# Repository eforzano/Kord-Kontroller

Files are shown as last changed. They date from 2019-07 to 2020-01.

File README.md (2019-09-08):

# Kord Kontroller
The Kord Kontroller is a MIDI controller that maps common chordal relationships in Western music theory. This pattern mapping allows you to play major, minor, and other common chords in the same pattern regardless of the key! The newest design is focusing on an ergonomic design based on your hand. For more information check out the [Hackaday page](https://hackaday.io/project/161105-kord-kontroller). 

## Theory  
The Kord Kontroller is a musical interface that maps the notes in the same pattern rather than being forced to memorize patterns that are caused by restrictions of acoustical phenomena (i.e. strings and metal). The advantage of being able to map the buttons in an intuitive way encourages music creation and lowers the threshold of learning music. The Kord Kontroller is laid out into two sections: the key selector area and tonal selector area. 

The three type of key selectors are a piano key selector, a circle of fifths key selector, and an isomorphic key selector. Once you select a note on the key selector, for example a C, this maps the tonal selectors in a consistent pattern regardless of the key. The tonal selectors are mapped to the 1 3 5 7 9 11 13 (C E G B D F A) of the key selected like below: 

```
3  5  7  9  11  13

1  
```

The 1 (or the root) and these corresponding notes are selected because they are really common chordal relationships. The 1 is mapped topographically lower on the controller in order to match your hand lay out and since it is commonly played with your thumb. This allows you to play major chords and other common chords in the same pattern regardless of the key!

We did not want to only let you play major chords so we added the flat and sharp equivalent rows: b3 b5 b7 b9 b11 b13 and #3 #5 #7 #9 #11 #13. (Note: we understand that it is not common to refer to the 4 as a #3 or the 8 as #7, but this is more to emphasize the relationships). This allows one to play minor chords and other chords in the exact same way as well. We also added some other common notes like the 2 b2 12 14 etc. We also added octave buttons and mode changes to switch the key selectors. This ended up with this final layout:
```
                       12    14
      4  #5   8   #9  #11   b14

2     3    5   7    9  11    13

b2    b3   b5  b7   b9 10   b13

1               6           #12

```

For any questions or comments email: eforzano at gmail.com

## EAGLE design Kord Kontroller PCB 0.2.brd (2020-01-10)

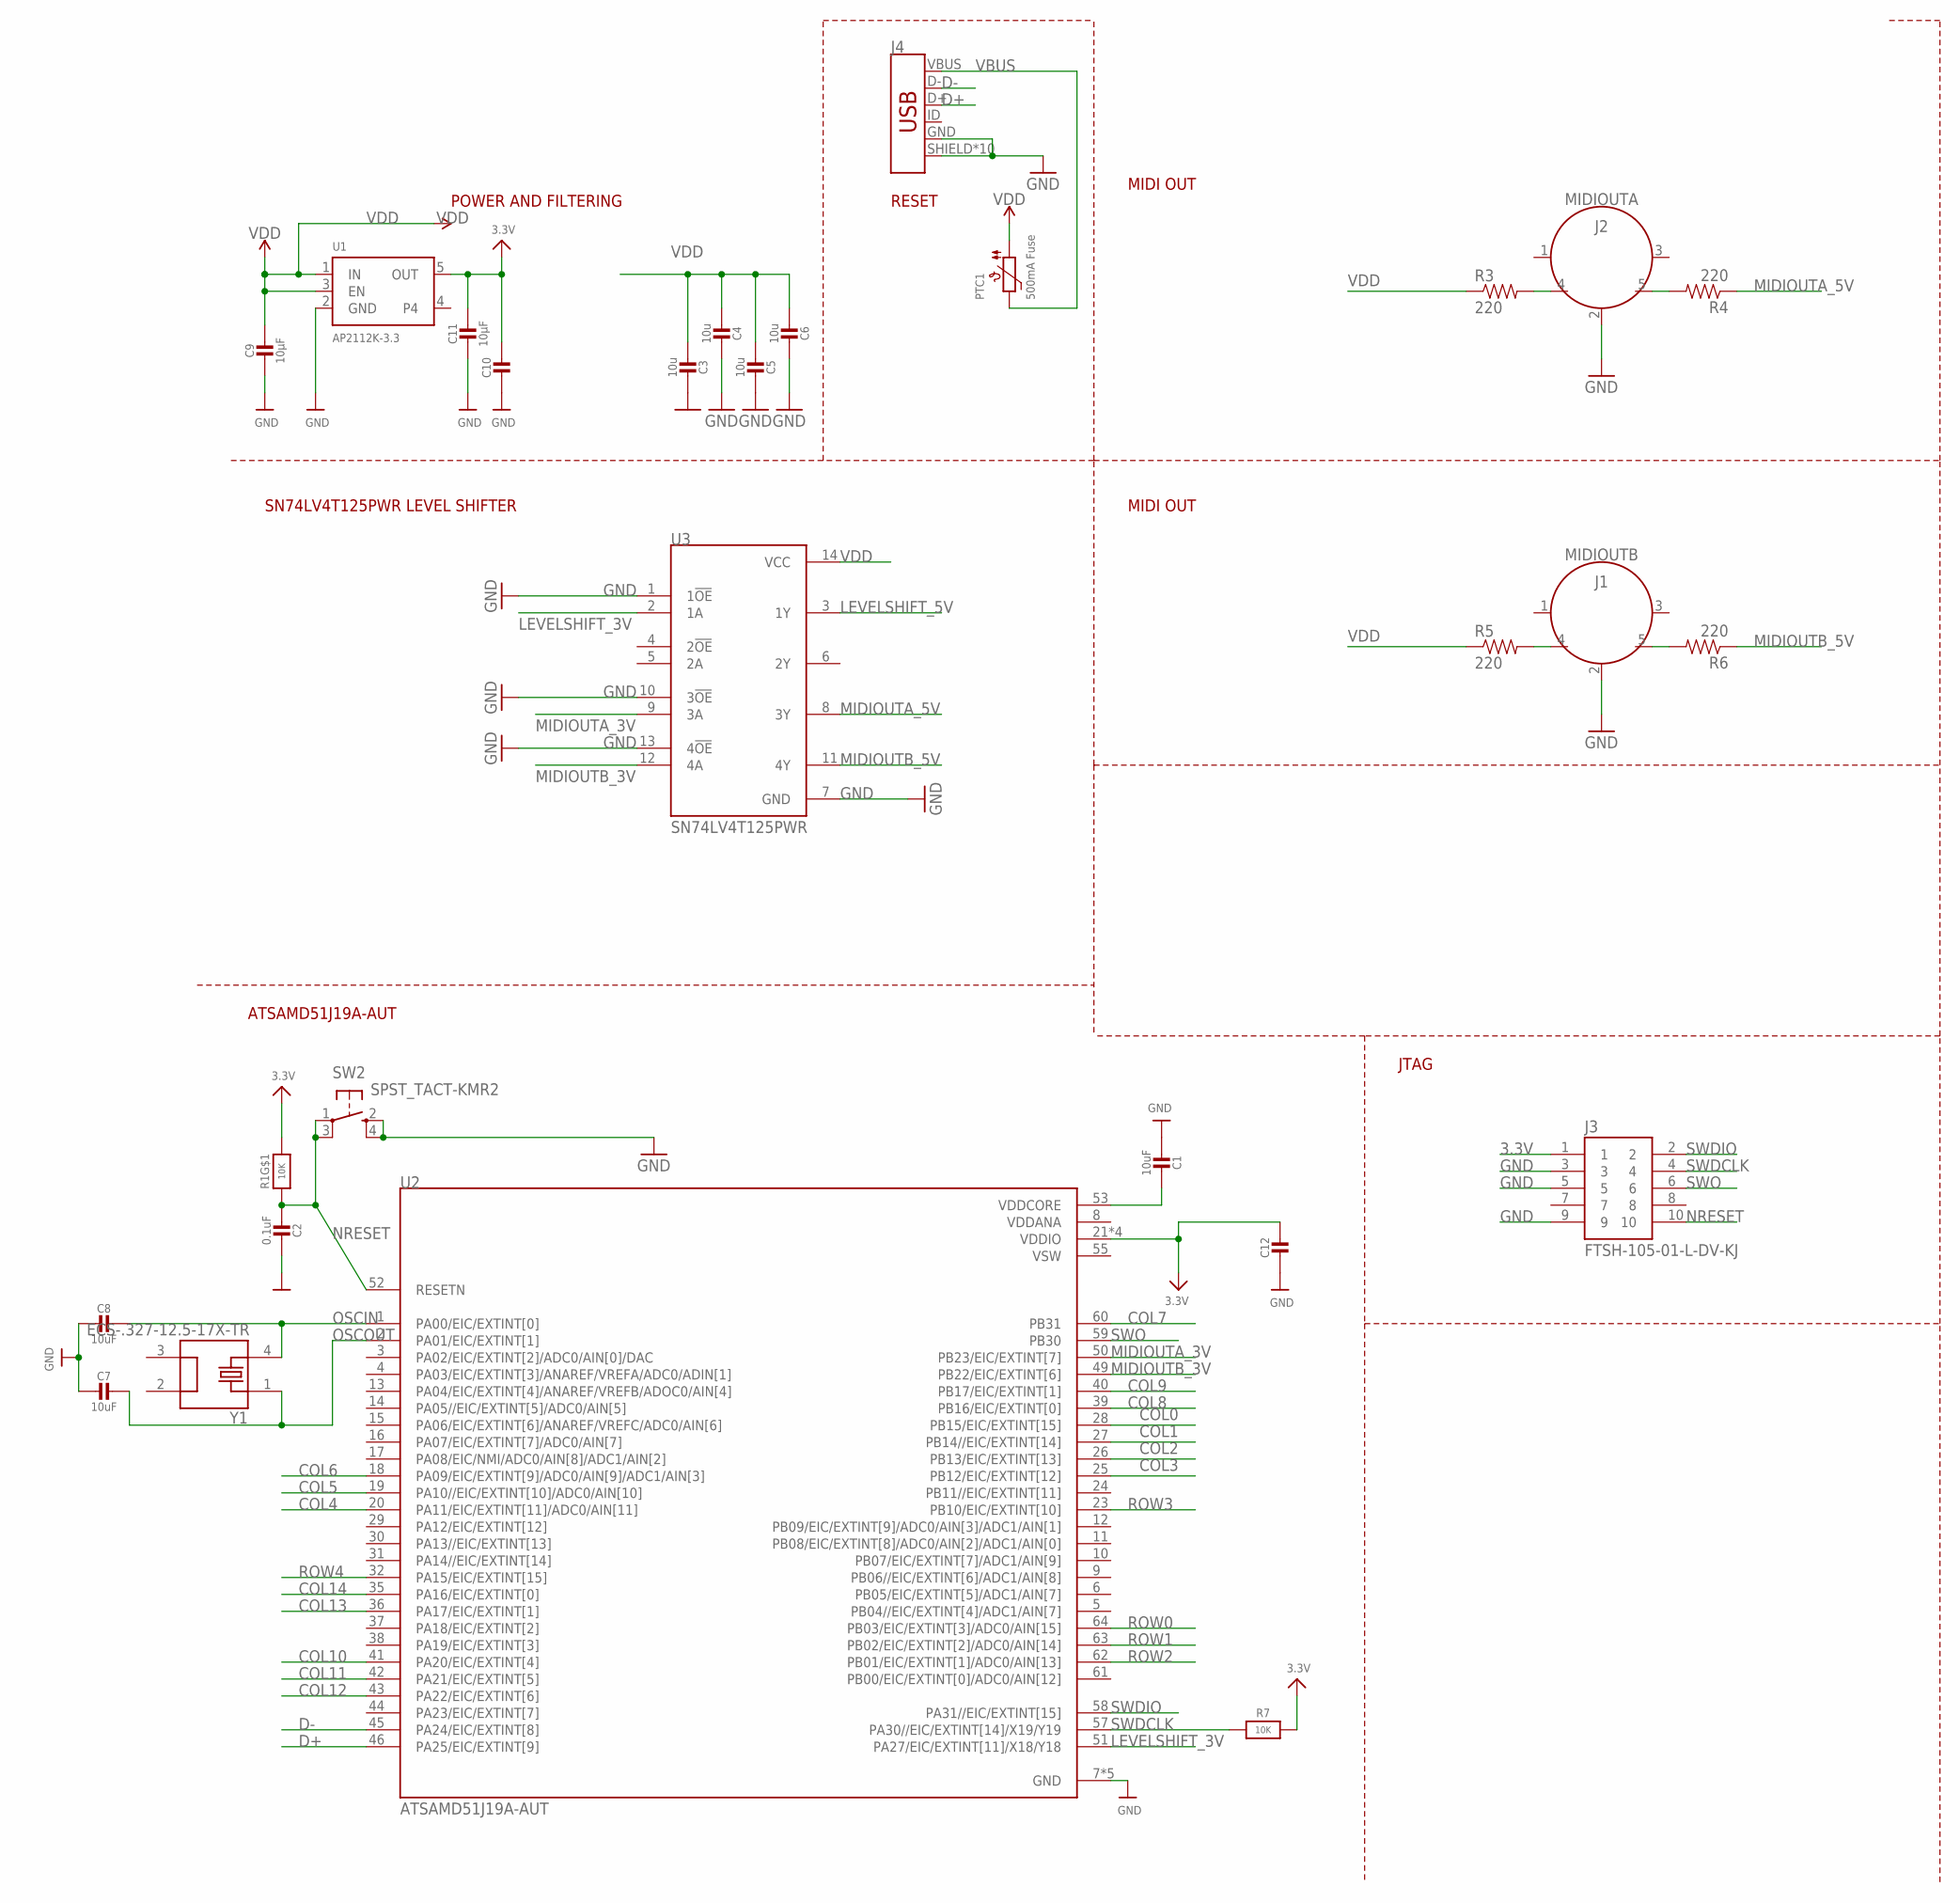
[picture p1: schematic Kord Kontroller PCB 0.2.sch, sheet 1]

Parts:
C1, C7, C8: 10uF; 0805-NO
C2: 0.1uF; 0603-NO
C3, C4, C5, C6: 10u; 0805-NO
C9, C11: 10µF; 0805-NO
C10, C12: 1uF; 0603-NO
J1: MIDIOUTB; 5-PIN-DIN-RA-PCB-NEW
J2: MIDIOUTA; 5-PIN-DIN-RA-PCB-NEW
J3: FTSH-105-01-L-DV-KJ; SAMTEC_FTSH-105-01-L-DV-K
J4: USB_MICRO-B_HALF_PTH_MILL; USB-MICROB-PTH-MILL
PTC1: 500mA Fuse; 1206
R1: 10K; RESPACK_4X0603
R3, R4, R5, R6: 220; 0603-RES
R7: 10K; 0603-NO
SW2: SPST_TACT-KMR2; KMR2
U1: AP2112K-3.3; SOT23-5
U2: ATSAMD51J19A-AUT; QFP50P1200X1200X120-64N
U3: SN74LV4T125PWR; SOP65P640X120-14N
Y1: ECS-.327-12.5-17X-TR; XTAL_ECS-.327-12.5-17X-TR

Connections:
3.3V: C10.1, C11.1, C12.1, J3.1, R1.8 (2), R7.2, U1.5 (OUT), U2.21 (VDDIO), U2.34 (VDDIO), U2.48 (VDDIO), U2.56 (VDDIO)
COL0: U2.28 (PB15/EIC/EXTINT[15]); also elsewhere on the board
COL1: U2.27 (PB14//EIC/EXTINT[14]); also elsewhere on the board
COL2: U2.26 (PB13/EIC/EXTINT[13]); also elsewhere on the board
COL3: U2.25 (PB12/EIC/EXTINT[12]); also elsewhere on the board
COL4: U2.20 (PA11/EIC/EXTINT[11]/ADC0/AIN[11]); also elsewhere on the board
COL5: U2.19 (PA10//EIC/EXTINT[10]/ADC0/AIN[10]); also elsewhere on the board
COL6: U2.18 (PA09/EIC/EXTINT[9]/ADC0/AIN[9]/ADC1/AIN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); also elsewhere on the board
COL7: U2.60 (PB31); also elsewhere on the board
COL8: U2.39 (PB16/EIC/EXTINT[0]); also elsewhere on the board
COL9: U2.40 (PB17/EIC/EXTINT[1]); also elsewhere on the board
COL10: U2.41 (PA20/EIC/EXTINT[4]); also elsewhere on the board
COL11: U2.42 (PA21/EIC/EXTINT[5]); also elsewhere on the board
COL12: U2.43 (PA22/EIC/EXTINT[6]); also elsewhere on the board
COL13: U2.36 (PA17/EIC/EXTINT[1]); also elsewhere on the board
COL14: U2.35 (PA16/EIC/EXTINT[0]); also elsewhere on the board
D+: J4.D+, U2.46 (PA25/EIC/EXTINT[9])
D-: J4.D-, U2.45 (PA24/EIC/EXTINT[8])
GND: C1.2, C2.1, C3.1, C4.1, C5.1, C6.1, C7.2, C8.2, C9.2, C10.2, C11.2, C12.2, J1.2, J2.2, J3.3, J3.5, J3.9, J4.GND, J4.SHIELD, J4.SHIELD2 (SHIELD), J4.SHIELD3 (SHIELD), J4.SHIELD4 (SHIELD), J4.SHIELD5 (SHIELD), J4.SHIELD6 (SHIELD), J4.SHIELD7 (SHIELD), J4.SHIELD8 (SHIELD), J4.SHIELD9 (SHIELD), J4.SHIELD10 (SHIELD), SW2.2 (S), SW2.4 (S1), U1.2 (GND), U2.7 (GND), U2.22 (GND), U2.33 (GND), U2.47 (GND), U2.54 (GND), U3.1 (1!OE), U3.7 (GND), U3.10 (3!OE), U3.13 (4!OE); also elsewhere on the board
LEVELSHIFT_3V: U2.51 (PA27/EIC/EXTINT[11]/X18/Y18), U3.2 (1A)
LEVELSHIFT_5V: U3.3 (1Y); also elsewhere on the board
MIDIOUTA_3V: U2.50 (PB23/EIC/EXTINT[7]), U3.9 (3A)
MIDIOUTA_5V: R4.1, U3.8 (3Y)
MIDIOUTB_3V: U2.49 (PB22/EIC/EXTINT[6]), U3.12 (4A)
MIDIOUTB_5V: R6.1, U3.11 (4Y)
unnamed: J1.5, R6.2
unnamed: J1.4, R5.2
unnamed: J2.5, R4.2
unnamed: J2.4, R3.2
NRESET: C2.2, J3.10, R1.1, SW2.1, SW2.3 (P1), U2.52 (RESETN)
OSCIN: C8.1, U2.1 (PA00/EIC/EXTINT[0]), Y1.4
OSCOUT: C7.1, U2.2 (PA01/EIC/EXTINT[1]), Y1.1
ROW0: U2.64 (PB03/EIC/EXTINT[3]/ADC0/AIN[15]); also elsewhere on the board
ROW1: U2.63 (PB02/EIC/EXTINT[2]/ADC0/AIN[14]); also elsewhere on the board
ROW2: U2.62 (PB01/EIC/EXTINT[1]/ADC0/AIN[13]); also elsewhere on the board
ROW3: U2.23 (PB10/EIC/EXTINT[10]); also elsewhere on the board
ROW4: U2.32 (PA15/EIC/EXTINT[15]); also elsewhere on the board
SWDCLK: J3.4, R7.1, U2.57 (PA30//EIC/EXTINT[14]/X19/Y19)
SWDIO: J3.2, U2.58 (PA31//EIC/EXTINT[15])
SWO: J3.6, U2.59 (PB30)
VBUS: J4.VBUS, PTC1.2
VDD: C3.2, C4.2, C5.2, C6.2, C9.1, PTC1.1, R3.1, R5.1, U1.1 (IN), U1.3 (EN), U3.14 (VCC); also elsewhere on the board
VDDANA: U2.8 (VDDANA)
VDDCORE1: C1.1, U2.53 (VDDCORE)
VSW: U2.55 (VSW)

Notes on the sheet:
POWER AND FILTERING
RESET
MIDI OUT
SN74LV4T125PWR LEVEL SHIFTER
JTAG
ATSAMD51J19A-AUT

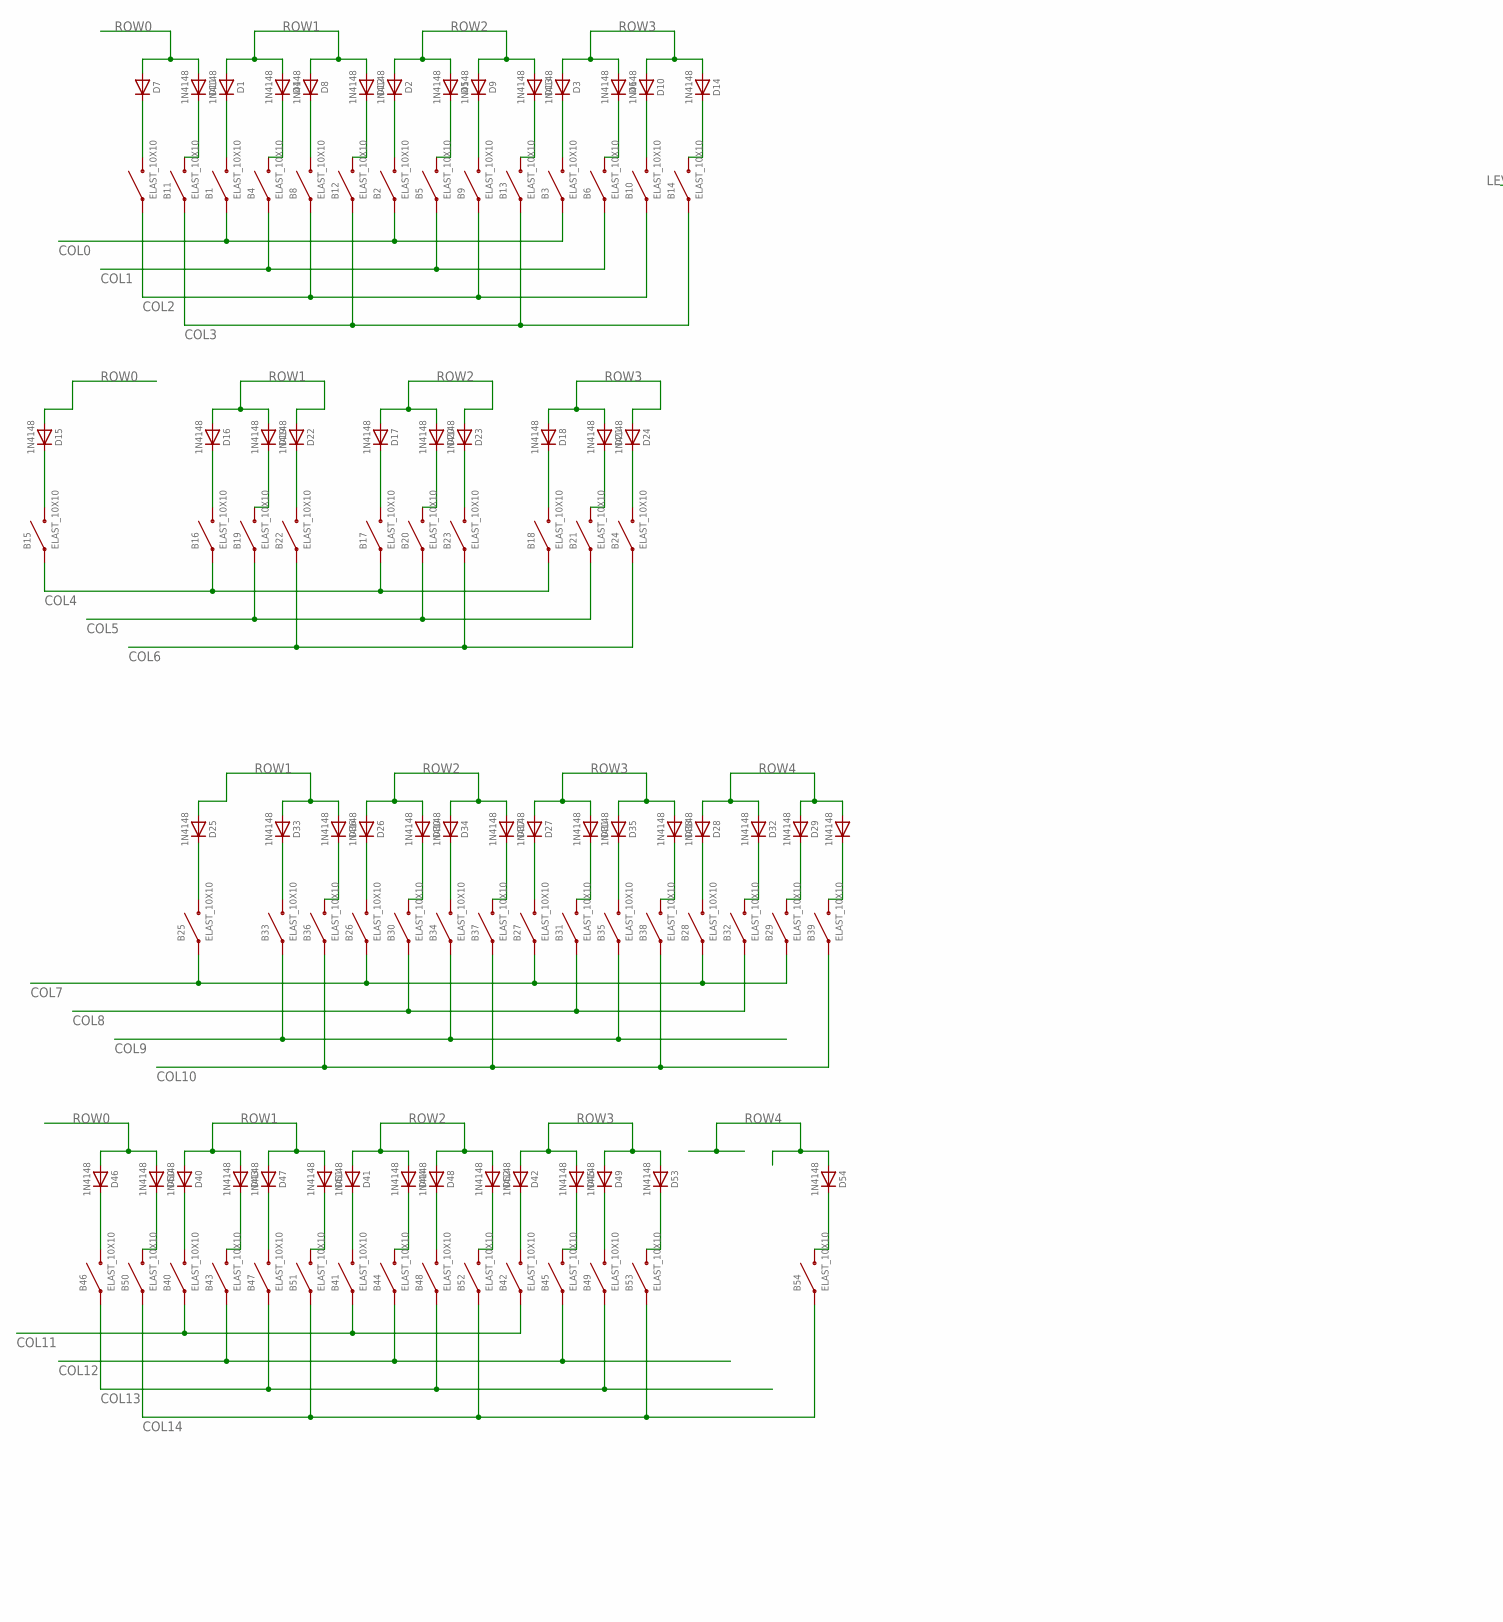
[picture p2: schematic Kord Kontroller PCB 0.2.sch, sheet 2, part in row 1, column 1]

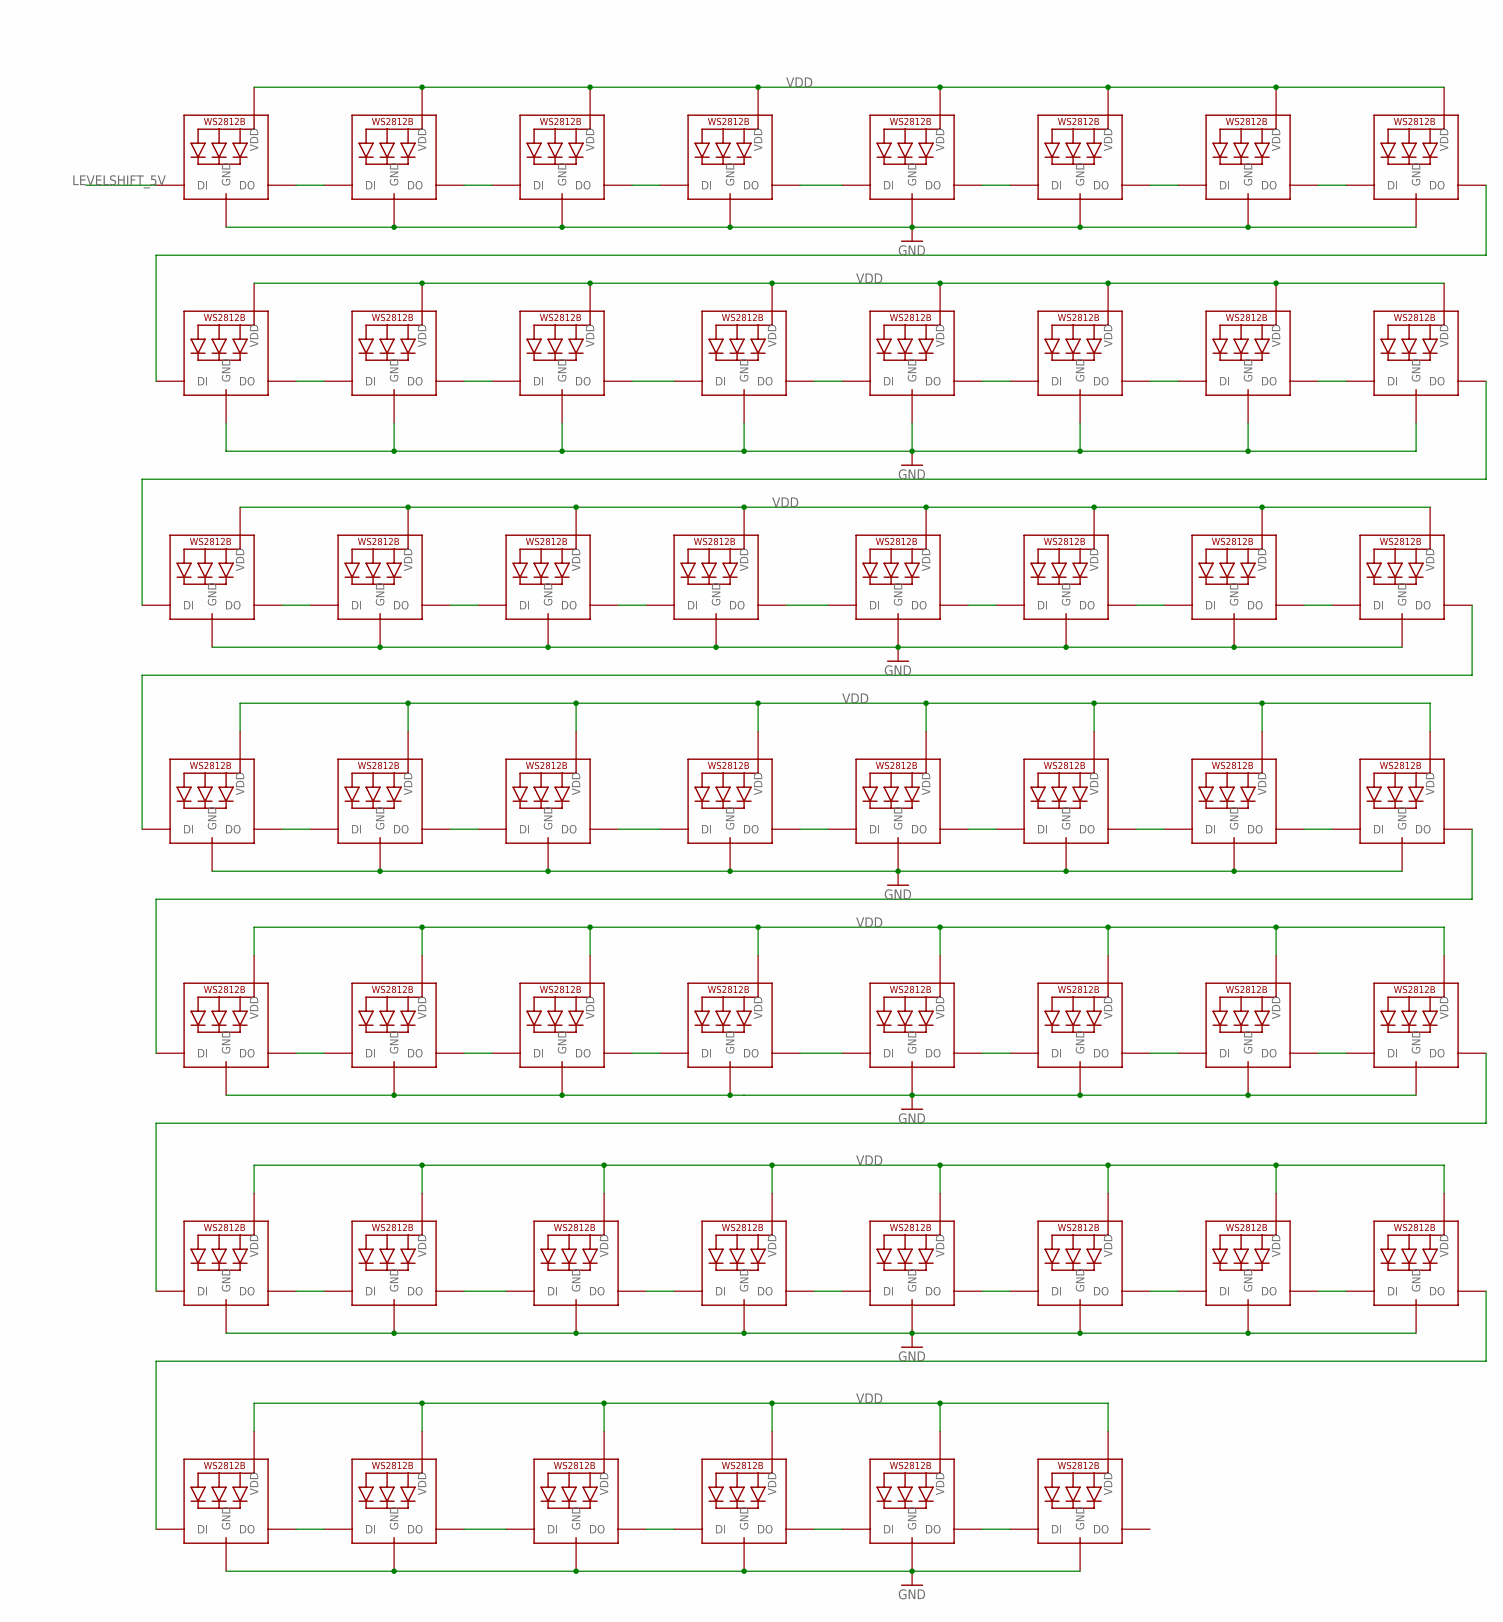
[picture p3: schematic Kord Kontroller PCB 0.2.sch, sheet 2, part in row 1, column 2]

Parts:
B1, B2, B3, B4, B5, B6, B7, B8, B9, B10, B11, B12, B13, B14, B15, B16, B17, B18, B19, B20, B21, B22, B23, B24, B25, B26, B27, B28, B29, B30, B31, B32, B33, B34, B35, B36, B37, B38, B39, B40, B41, B42, B43, B44, B45, B46, B47, B48, B49, B50, B51, B52, B53, B54: ELAST_10X10; ELAST_PAD_SQUARE_10MM_4X4WIDE
D1, D2, D3, D4, D5, D6, D7, D8, D9, D10, D11, D12, D13, D14, D15, D16, D17, D18, D19, D20, D21, D22, D23, D24, D25, D26, D27, D28, D29, D30, D31, D32, D33, D34, D35, D36, D37, D38, D39, D40, D41, D42, D43, D44, D45, D46, D47, D48, D49, D50, D51, D52, D53, D54: 1N4148; SOD-323
LED1, LED2, LED3, LED4, LED5, LED6, LED7, LED8, LED9, LED10, LED11, LED12, LED13, LED14, LED15, LED16, LED17, LED18, LED19, LED20, LED21, LED22, LED23, LED24, LED25, LED26, LED27, LED28, LED29, LED30, LED31, LED32, LED33, LED34, LED35, LED36, LED37, LED38, LED39, LED40, LED41, LED42, LED43, LED44, LED45, LED46, LED47, LED48, LED49, LED50, LED51, LED52, LED53, LED54: WS2812B3535; LED3535

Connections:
COL0: B1.P$1, B2.P$1, B3.P$1; also elsewhere on the board
COL1: B4.P$1, B5.P$1, B6.P$1; also elsewhere on the board
COL2: B7.P$1, B8.P$1, B9.P$1, B10.P$1; also elsewhere on the board
COL3: B11.P$1, B12.P$1, B13.P$1, B14.P$1; also elsewhere on the board
COL4: B15.P$1, B16.P$1, B17.P$1, B18.P$1; also elsewhere on the board
COL5: B19.P$1, B20.P$1, B21.P$1; also elsewhere on the board
COL6: B22.P$1, B23.P$1, B24.P$1; also elsewhere on the board
COL7: B25.P$1, B26.P$1, B27.P$1, B28.P$1, B29.P$1; also elsewhere on the board
COL8: B30.P$1, B31.P$1, B32.P$1; also elsewhere on the board
COL9: B33.P$1, B34.P$1, B35.P$1; also elsewhere on the board
COL10: B36.P$1, B37.P$1, B38.P$1, B39.P$1; also elsewhere on the board
COL11: B40.P$1, B41.P$1, B42.P$1; also elsewhere on the board
COL12: B43.P$1, B44.P$1, B45.P$1; also elsewhere on the board
COL13: B46.P$1, B47.P$1, B48.P$1, B49.P$1; also elsewhere on the board
COL14: B50.P$1, B51.P$1, B52.P$1, B53.P$1, B54.P$1; also elsewhere on the board
GND: LED1.4 (GND), LED2.4 (GND), LED3.4 (GND), LED4.4 (GND), LED5.4 (GND), LED6.4 (GND), LED7.4 (GND), LED8.4 (GND), LED9.4 (GND), LED10.4 (GND), LED11.4 (GND), LED12.4 (GND), LED13.4 (GND), LED14.4 (GND), LED15.4 (GND), LED16.4 (GND), LED17.4 (GND), LED18.4 (GND), LED19.4 (GND), LED20.4 (GND), LED21.4 (GND), LED22.4 (GND), LED23.4 (GND), LED24.4 (GND), LED25.4 (GND), LED26.4 (GND), LED27.4 (GND), LED28.4 (GND), LED29.4 (GND), LED30.4 (GND), LED31.4 (GND), LED32.4 (GND), LED33.4 (GND), LED34.4 (GND), LED35.4 (GND), LED36.4 (GND), LED37.4 (GND), LED38.4 (GND), LED39.4 (GND), LED40.4 (GND), LED41.4 (GND), LED42.4 (GND), LED43.4 (GND), LED44.4 (GND), LED45.4 (GND), LED46.4 (GND), LED47.4 (GND), LED48.4 (GND), LED49.4 (GND), LED50.4 (GND), LED51.4 (GND), LED52.4 (GND), LED53.4 (GND), LED54.4 (GND); also elsewhere on the board
LEVELSHIFT_5V: LED1.1 (DI); also elsewhere on the board
unnamed: LED36.3 (DO), LED37.1 (DI)
unnamed: B7.P$2, D7.C
unnamed: B11.P$2, D11.C
unnamed: B1.P$2, D1.C
unnamed: LED17.3 (DO), LED18.1 (DI)
unnamed: LED18.3 (DO), LED19.1 (DI)
unnamed: B4.P$2, D4.C
unnamed: LED19.3 (DO), LED20.1 (DI)
unnamed: LED1.3 (DO), LED2.1 (DI)
unnamed: LED2.3 (DO), LED3.1 (DI)
unnamed: LED3.3 (DO), LED4.1 (DI)
unnamed: LED4.3 (DO), LED5.1 (DI)
unnamed: B8.P$2, D8.C
unnamed: LED5.3 (DO), LED6.1 (DI)
unnamed: LED6.3 (DO), LED7.1 (DI)
unnamed: B12.P$2, D12.C
unnamed: LED7.3 (DO), LED8.1 (DI)
unnamed: B2.P$2, D2.C
unnamed: LED8.3 (DO), LED9.1 (DI)
unnamed: B5.P$2, D5.C
unnamed: B9.P$2, D9.C
unnamed: B13.P$2, D13.C
unnamed: B3.P$2, D3.C
unnamed: B6.P$2, D6.C
unnamed: B10.P$2, D10.C
unnamed: B14.P$2, D14.C
unnamed: LED9.3 (DO), LED10.1 (DI)
unnamed: LED10.3 (DO), LED11.1 (DI)
unnamed: LED11.3 (DO), LED12.1 (DI)
unnamed: LED12.3 (DO), LED13.1 (DI)
unnamed: LED13.3 (DO), LED14.1 (DI)
unnamed: LED14.3 (DO), LED15.1 (DI)
unnamed: LED15.3 (DO), LED16.1 (DI)
unnamed: LED20.3 (DO), LED21.1 (DI)
unnamed: LED21.3 (DO), LED22.1 (DI)
unnamed: LED22.3 (DO), LED23.1 (DI)
unnamed: LED23.3 (DO), LED24.1 (DI)
unnamed: LED24.3 (DO), LED25.1 (DI)
unnamed: LED25.3 (DO), LED26.1 (DI)
unnamed: LED26.3 (DO), LED27.1 (DI)
unnamed: LED28.3 (DO), LED29.1 (DI)
unnamed: LED27.3 (DO), LED28.1 (DI)
unnamed: LED29.3 (DO), LED30.1 (DI)
unnamed: LED30.3 (DO), LED31.1 (DI)
unnamed: LED31.3 (DO), LED32.1 (DI)
unnamed: B15.P$2, D15.C
unnamed: LED34.3 (DO), LED35.1 (DI)
unnamed: LED35.3 (DO), LED36.1 (DI)
unnamed: LED44.3 (DO), LED45.1 (DI)
unnamed: B16.P$2, D16.C
unnamed: B19.P$2, D19.C
unnamed: B22.P$2, D22.C
unnamed: LED43.3 (DO), LED44.1 (DI)
unnamed: B17.P$2, D17.C
unnamed: B20.P$2, D20.C
unnamed: B23.P$2, D23.C
unnamed: LED42.3 (DO), LED43.1 (DI)
unnamed: B18.P$2, D18.C
unnamed: B21.P$2, D21.C
unnamed: B24.P$2, D24.C
unnamed: LED16.3 (DO), LED17.1 (DI)
unnamed: LED50.3 (DO), LED51.1 (DI)
unnamed: LED51.3 (DO), LED52.1 (DI)
unnamed: LED52.3 (DO), LED53.1 (DI)
unnamed: B29.P$2, D29.C
unnamed: B25.P$2, D25.C
unnamed: B33.P$2, D33.C
unnamed: B36.P$2, D36.C
unnamed: B26.P$2, D26.C
unnamed: B30.P$2, D30.C
unnamed: B34.P$2, D34.C
unnamed: B37.P$2, D37.C
unnamed: B27.P$2, D27.C
unnamed: B31.P$2, D31.C
unnamed: B35.P$2, D35.C
unnamed: B38.P$2, D38.C
unnamed: LED33.3 (DO), LED34.1 (DI)
unnamed: LED37.3 (DO), LED38.1 (DI)
unnamed: LED38.3 (DO), LED39.1 (DI)
unnamed: LED39.3 (DO), LED40.1 (DI)
unnamed: LED41.3 (DO), LED42.1 (DI)
unnamed: LED45.3 (DO), LED46.1 (DI)
unnamed: LED46.3 (DO), LED47.1 (DI)
unnamed: LED47.3 (DO), LED48.1 (DI)
unnamed: LED49.3 (DO), LED50.1 (DI)
unnamed: LED53.3 (DO), LED54.1 (DI)
unnamed: LED40.3 (DO), LED41.1 (DI)
unnamed: LED48.3 (DO), LED49.1 (DI)
unnamed: LED32.3 (DO), LED33.1 (DI)
unnamed: B46.P$2, D46.C
unnamed: B50.P$2, D50.C
unnamed: B40.P$2, D40.C
unnamed: B43.P$2, D43.C
unnamed: B47.P$2, D47.C
unnamed: B51.P$2, D51.C
unnamed: B41.P$2, D41.C
unnamed: B44.P$2, D44.C
unnamed: B48.P$2, D48.C
unnamed: B52.P$2, D52.C
unnamed: B42.P$2, D42.C
unnamed: B45.P$2, D45.C
unnamed: B49.P$2, D49.C
unnamed: B53.P$2, D53.C
unnamed: B28.P$2, D28.C
unnamed: B32.P$2, D32.C
unnamed: B39.P$2, D39.C
unnamed: B54.P$2, D54.C
ROW0: D7.A, D11.A, D15.A, D46.A, D50.A; also elsewhere on the board
ROW1: D1.A, D4.A, D8.A, D12.A, D16.A, D19.A, D22.A, D25.A, D33.A, D36.A, D40.A, D43.A, D47.A, D51.A; also elsewhere on the board
ROW2: D2.A, D5.A, D9.A, D13.A, D17.A, D20.A, D23.A, D26.A, D30.A, D34.A, D37.A, D41.A, D44.A, D48.A, D52.A; also elsewhere on the board
ROW3: D3.A, D6.A, D10.A, D14.A, D18.A, D21.A, D24.A, D27.A, D31.A, D35.A, D38.A, D42.A, D45.A, D49.A, D53.A; also elsewhere on the board
ROW4: D28.A, D29.A, D32.A, D39.A, D54.A; also elsewhere on the board
VDD: LED1.2 (VDD), LED2.2 (VDD), LED3.2 (VDD), LED4.2 (VDD), LED5.2 (VDD), LED6.2 (VDD), LED7.2 (VDD), LED8.2 (VDD), LED9.2 (VDD), LED10.2 (VDD), LED11.2 (VDD), LED12.2 (VDD), LED13.2 (VDD), LED14.2 (VDD), LED15.2 (VDD), LED16.2 (VDD), LED17.2 (VDD), LED18.2 (VDD), LED19.2 (VDD), LED20.2 (VDD), LED21.2 (VDD), LED22.2 (VDD), LED23.2 (VDD), LED24.2 (VDD), LED25.2 (VDD), LED26.2 (VDD), LED27.2 (VDD), LED28.2 (VDD), LED29.2 (VDD), LED30.2 (VDD), LED31.2 (VDD), LED32.2 (VDD), LED33.2 (VDD), LED34.2 (VDD), LED35.2 (VDD), LED36.2 (VDD), LED37.2 (VDD), LED38.2 (VDD), LED39.2 (VDD), LED40.2 (VDD), LED41.2 (VDD), LED42.2 (VDD), LED43.2 (VDD), LED44.2 (VDD), LED45.2 (VDD), LED46.2 (VDD), LED47.2 (VDD), LED48.2 (VDD), LED49.2 (VDD), LED50.2 (VDD), LED51.2 (VDD), LED52.2 (VDD), LED53.2 (VDD), LED54.2 (VDD); also elsewhere on the board

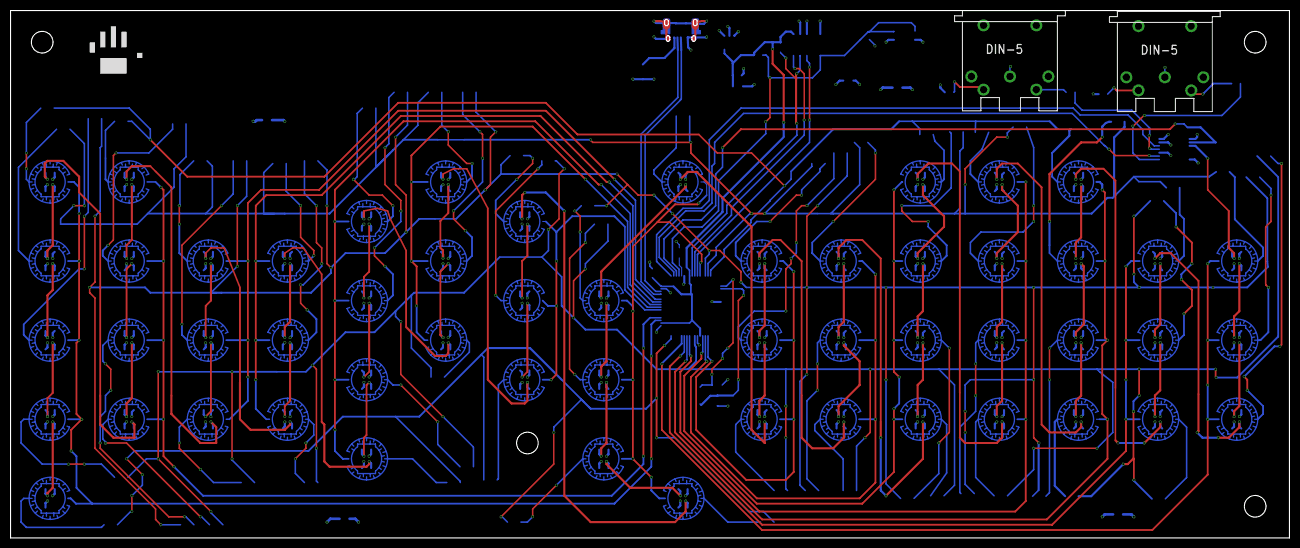
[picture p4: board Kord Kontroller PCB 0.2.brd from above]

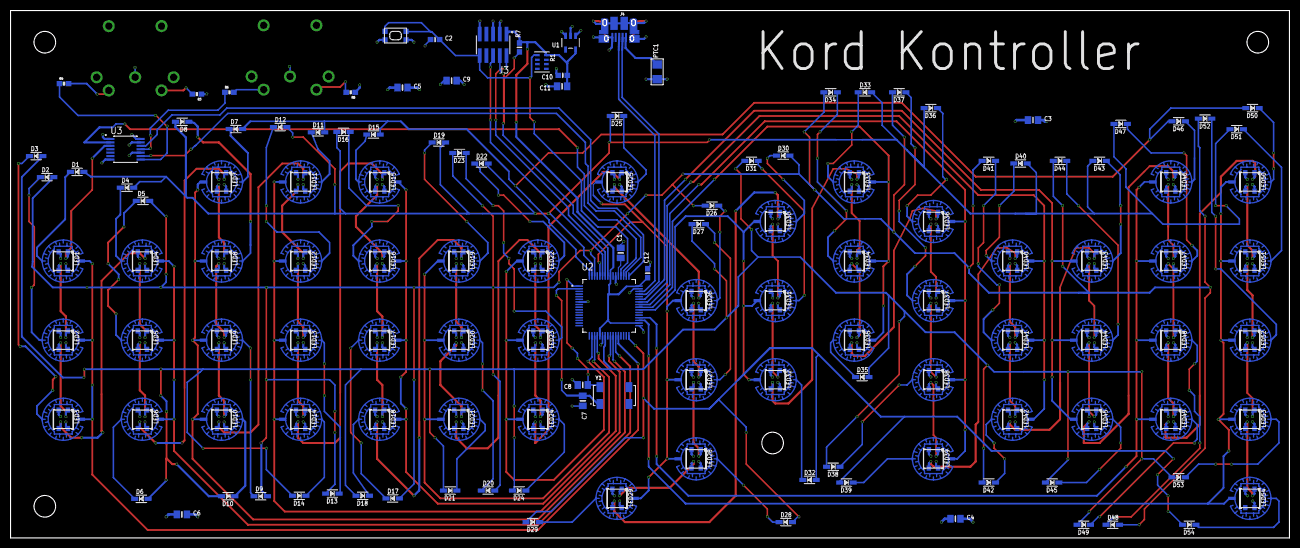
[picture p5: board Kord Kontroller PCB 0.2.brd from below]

Board: 4 copper layers, 242.5 x 100.0 mm, 190 parts (188 on the bottom side), 150 nets.

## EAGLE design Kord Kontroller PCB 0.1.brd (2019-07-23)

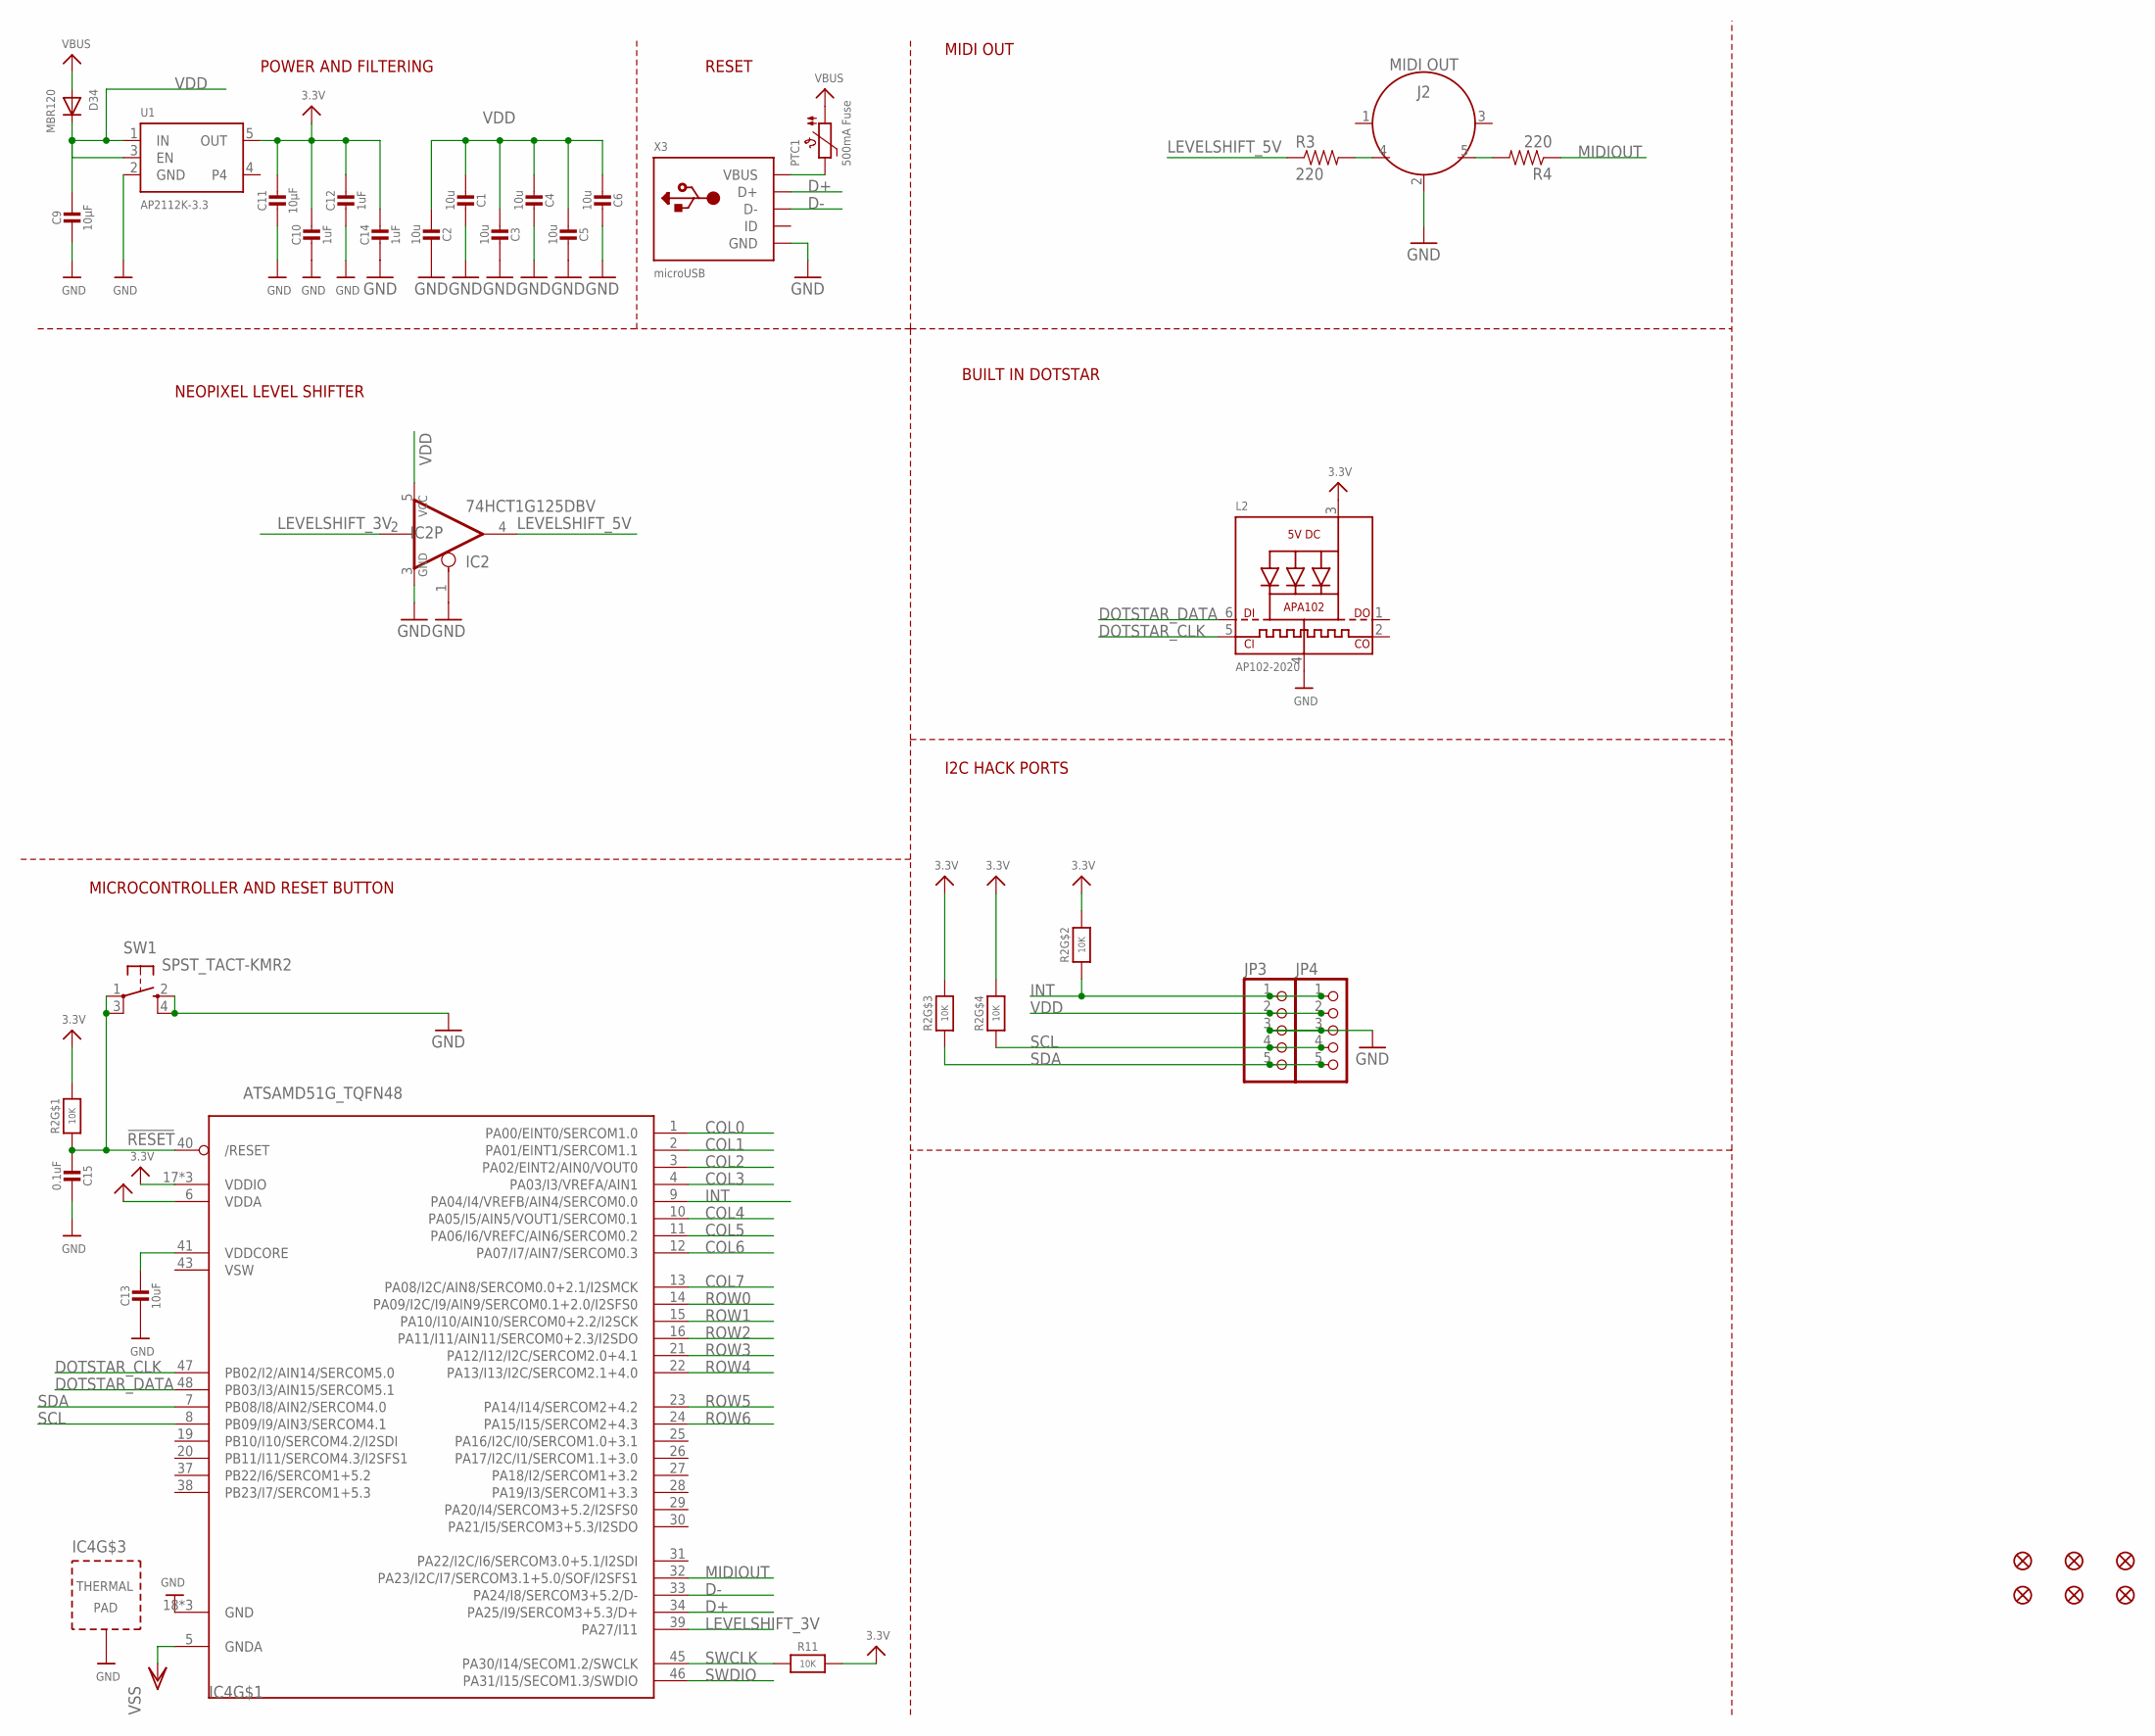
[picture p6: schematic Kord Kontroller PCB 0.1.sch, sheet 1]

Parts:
C1, C2, C3, C4, C5, C6: 10u; 0805-NO
C9, C11: 10µF; 0805-NO
C10, C12, C14: 1uF; 0603-NO
C13: 10uF; 0805-NO
C15: 0.1uF; 0603-NO
D34: MBR120; SOD-123FL
FID1, FID2, FID3, FID4, FID5, FID6: FIDUCIAL_1MM
IC2: 74HCT1G125DBV; SOT23-5
IC4: ATSAMD51G_TQFN48; TQFN48_7MM
J2: MIDI OUT; 5-PIN-DIN-RA-PCB-NEW
JP3, JP4: HEADER-1X5EDGESMT; 5P_EDGECONNECT
L2: AP102-2020; APA102_2020
PTC1: 500mA Fuse; 1206
R2: 10K; RESPACK_4X0603
R3, R4: 220; 0603-RES
R11: 10K; 0603-NO
SW1: SPST_TACT-KMR2; KMR2
U1: AP2112K-3.3; SOT23-5
X3: microUSB; 4UCONN_20329_NARROW

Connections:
3.3V: C10.1, C11.1, C12.1, C14.1, IC4.17 (VDDIO), IC4.36 (VDDIO), IC4.44 (VDDIO), L2.3 (VDD), R2.5 (2), R2.6 (2), R2.7 (2), R2.8 (2), R11.2, U1.5 (OUT)
!RESET: C15.2, IC4.40 (/RESET), R2.1, SW1.1, SW1.3 (P1)
AVDD: IC4.6 (VDDA)
COL0: IC4.1 (PA00/EINT0/SERCOM1.0); also elsewhere on the board
COL1: IC4.2 (PA01/EINT1/SERCOM1.1); also elsewhere on the board
COL2: IC4.3 (PA02/EINT2/AIN0/VOUT0); also elsewhere on the board
COL3: IC4.4 (PA03/I3/VREFA/AIN1); also elsewhere on the board
COL4: IC4.10 (PA05/I5/AIN5/VOUT1/SERCOM0.1); also elsewhere on the board
COL5: IC4.11 (PA06/I6/VREFC/AIN6/SERCOM0.2); also elsewhere on the board
COL6: IC4.12 (PA07/I7/AIN7/SERCOM0.3); also elsewhere on the board
COL7: IC4.13 (PA08/I2C/AIN8/SERCOM0.0+2.1/I2SMCK); also elsewhere on the board
D+: IC4.34 (PA25/I9/SERCOM3+5.3/D+), X3.D+
D-: IC4.33 (PA24/I8/SERCOM3+5.2/D-), X3.D-
DOTSTAR_CLK: IC4.47 (PB02/I2/AIN14/SERCOM5.0), L2.5 (CKI)
DOTSTAR_DATA: IC4.48 (PB03/I3/AIN15/SERCOM5.1), L2.6 (DI)
GND: C1.1, C2.1, C3.1, C4.1, C5.1, C6.1, C9.2, C10.2, C11.2, C12.2, C13.2, C14.2, C15.1, IC2.1 (OE), IC2.3 (GND), IC4.18 (GND), IC4.35 (GND), IC4.42 (GND), IC4.THERMAL (TP), J2.2, JP3.3, JP4.3, L2.4 (GND), SW1.2 (S), SW1.4 (S1), U1.2 (GND), X3.BASE@1 (GND), X3.BASE@2 (GND), X3.GND, X3.SPRT@1 (GND), X3.SPRT@2 (GND), X3.SPRT@3 (GND), X3.SPRT@4 (GND); also elsewhere on the board
INT: IC4.9 (PA04/I4/VREFB/AIN4/SERCOM0.0), JP3.1, JP4.1, R2.2 (1)
unnamed: PTC1.2, X3.VBUS
NEOPIXEL_3V: IC2.2 (I), IC4.39 (PA27/I11); also elsewhere on the board
unnamed: IC2.4 (O), R3.1
unnamed: J2.4, R3.2
unnamed: J2.5, R4.2
unnamed: IC4.32 (PA23/I2C/I7/SERCOM3.1+5.0/SOF/I2SFS1), R4.1
ROW0: IC4.14 (PA09/I2C/I9/AIN9/SERCOM0.1+2.0/I2SFS0); also elsewhere on the board
ROW1: IC4.15 (PA10/I10/AIN10/SERCOM0+2.2/I2SCK); also elsewhere on the board
ROW2: IC4.16 (PA11/I11/AIN11/SERCOM0+2.3/I2SDO); also elsewhere on the board
ROW3: IC4.21 (PA12/I12/I2C/SERCOM2.0+4.1); also elsewhere on the board
ROW4: IC4.22 (PA13/I13/I2C/SERCOM2.1+4.0); also elsewhere on the board
ROW5: IC4.23 (PA14/I14/SERCOM2+4.2); also elsewhere on the board
ROW6: IC4.24 (PA15/I15/SERCOM2+4.3); also elsewhere on the board
SCL: IC4.8 (PB09/I9/AIN3/SERCOM4.1), JP3.4, JP4.4, R2.4 (1)
SDA: IC4.7 (PB08/I8/AIN2/SERCOM4.0), JP3.5, JP4.5, R2.3 (1)
SWCLK: IC4.45 (PA30/I14/SECOM1.2/SWCLK), R11.1
SWDIO: IC4.46 (PA31/I15/SECOM1.3/SWDIO)
VBUS: D34.A, PTC1.1
VDD: C1.2, C2.2, C3.2, C4.2, C5.2, C6.2, C9.1, D34.C, IC2.5 (VCC), JP3.2, JP4.2, U1.1 (IN), U1.3 (EN); also elsewhere on the board
VDDCORE: C13.1, IC4.41 (VDDCORE)
VSS: IC4.5 (GNDA)
VSW: IC4.43 (VSW)

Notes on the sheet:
POWER AND FILTERING
RESET
BUILT IN DOTSTAR
I2C HACK PORTS
MICROCONTROLLER AND RESET BUTTON
MIDI OUT
NEOPIXEL LEVEL SHIFTER

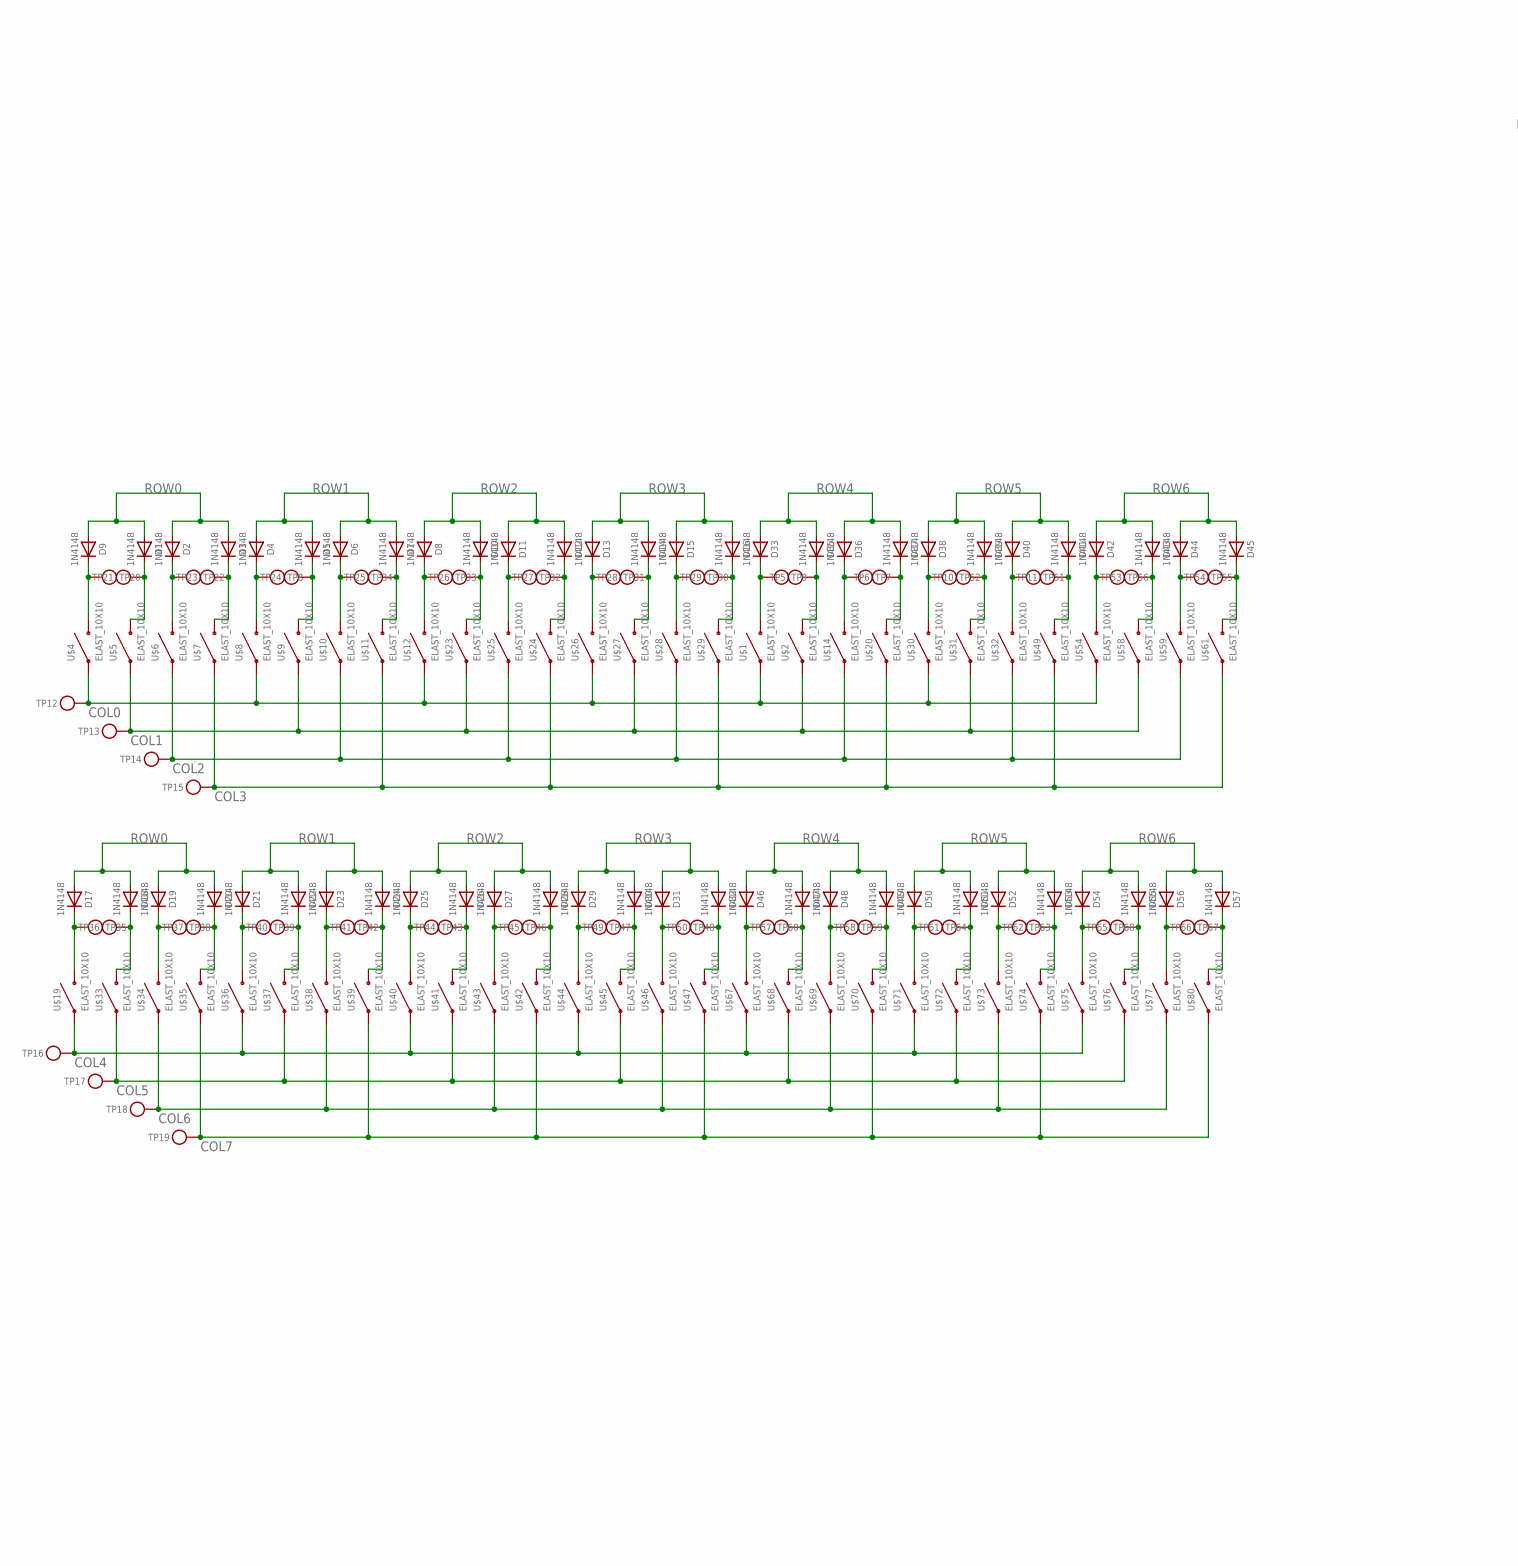
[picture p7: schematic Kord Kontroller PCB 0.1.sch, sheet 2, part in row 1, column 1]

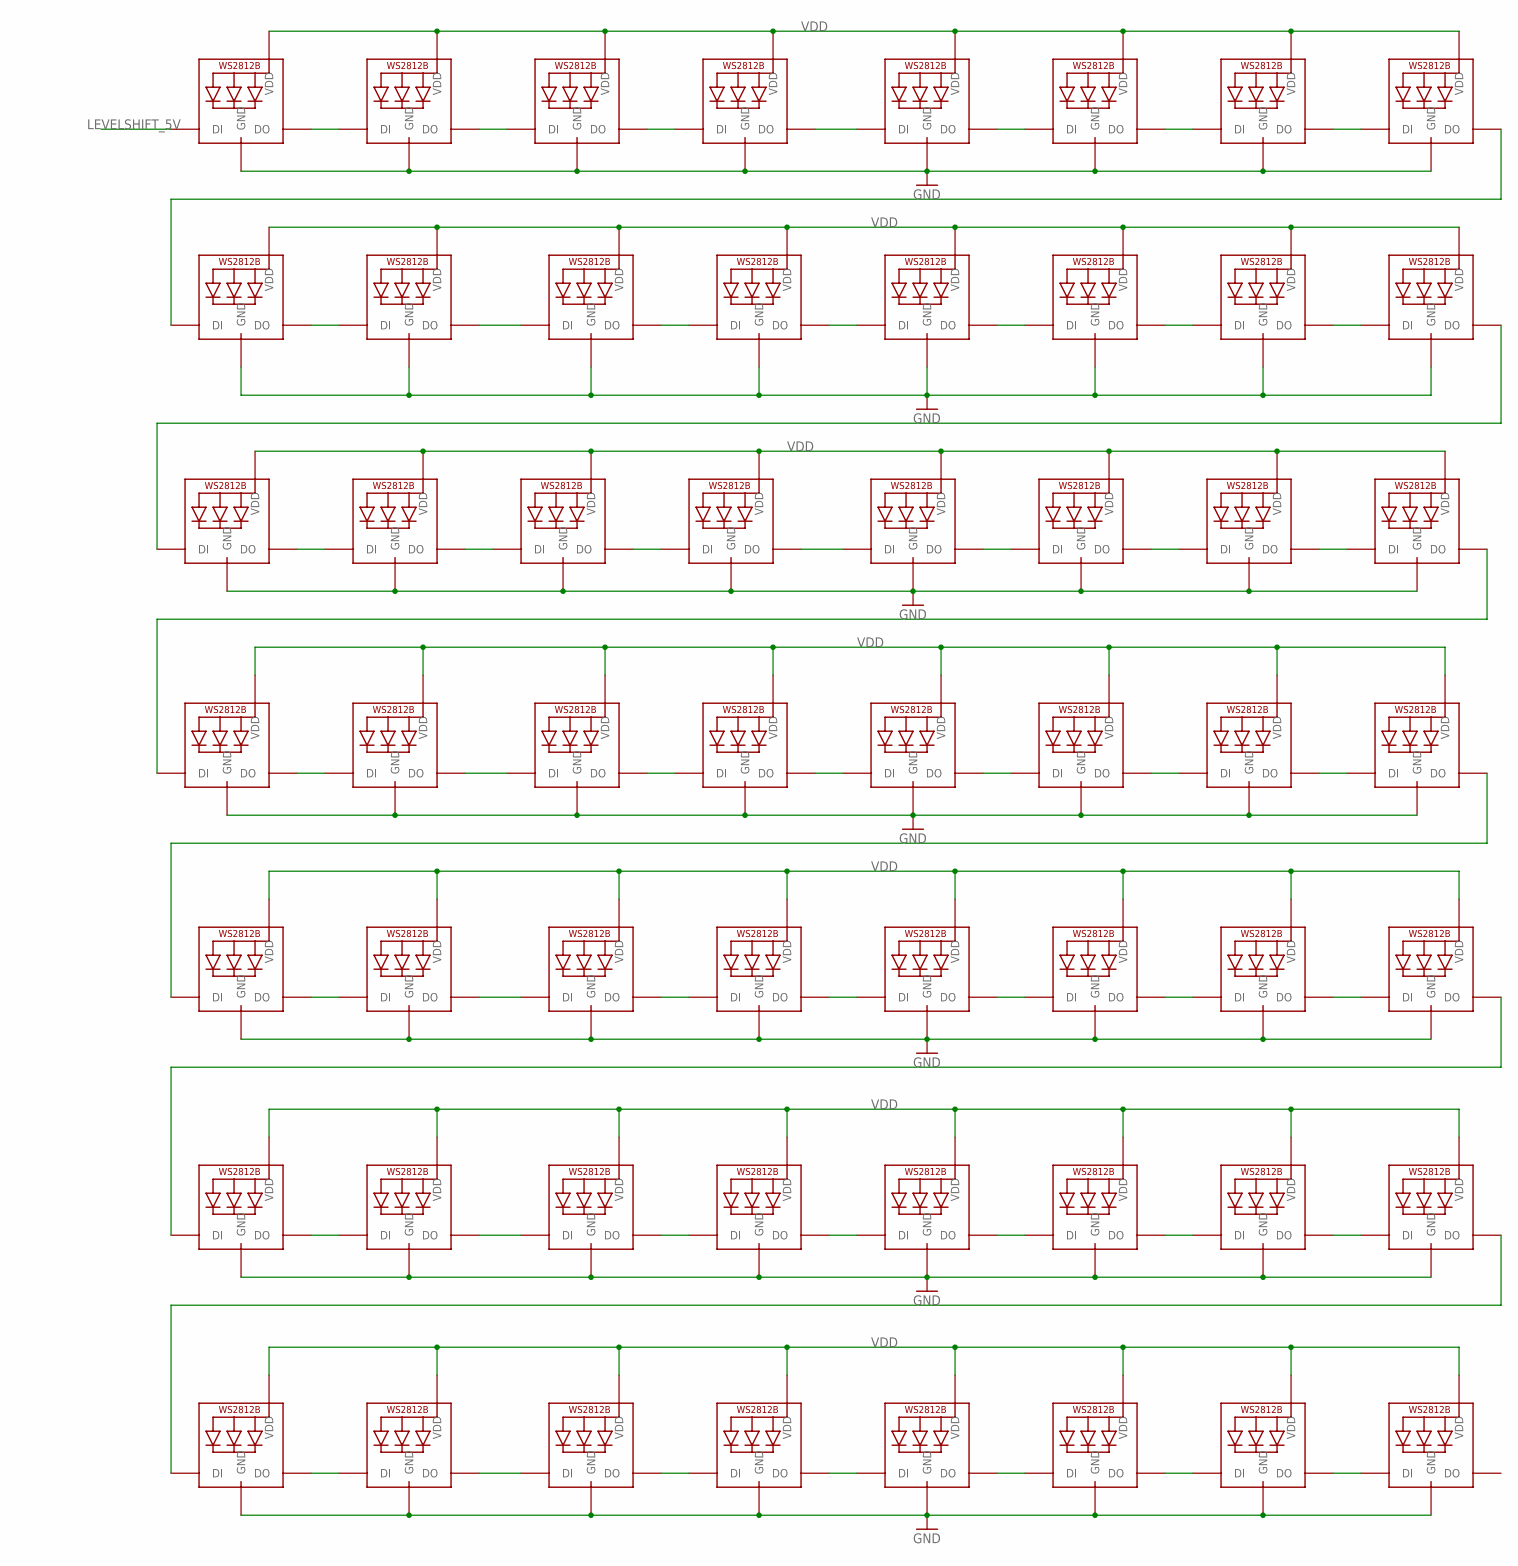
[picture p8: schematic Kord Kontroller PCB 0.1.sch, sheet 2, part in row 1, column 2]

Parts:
D1, D2, D3, D4, D5, D6, D7, D8, D9, D10, D11, D12, D13, D14, D15, D16, D17, D18, D19, D20, D21, D22, D23, D24, D25, D26, D27, D28, D29, D30, D31, D32, D33, D35, D36, D37, D38, D39, D40, D41, D42, D43, D44, D45, D46, D47, D48, D49, D50, D51, D52, D53, D54, D55, D56, D57: 1N4148; SOD-323
LED1, LED2, LED3, LED4, LED5, LED6, LED7, LED8, LED9, LED10, LED11, LED12, LED13, LED14, LED15, LED16, LED17, LED18, LED19, LED20, LED21, LED22, LED23, LED24, LED25, LED26, LED27, LED28, LED29, LED30, LED31, LED32, LED33, LED34, LED35, LED36, LED37, LED38, LED39, LED40, LED41, LED42, LED43, LED44, LED45, LED46, LED47, LED48, LED49, LED50, LED51, LED52, LED53, LED54, LED55, LED56: WS2812B3535; LED3535
TP5, TP6, TP7, TP8, TP9, TP10, TP11, TP12, TP13, TP14, TP15, TP16, TP17, TP18, TP19, TP20, TP21, TP22, TP23, TP24, TP25, TP26, TP27, TP28, TP29, TP30, TP31, TP32, TP33, TP34, TP35, TP36, TP37, TP38, TP39, TP40, TP41, TP42, TP43, TP44, TP45, TP46, TP47, TP48, TP49, TP50, TP51, TP52, TP53, TP54, TP55, TP56, TP57, TP58, TP59, TP60, TP61, TP62, TP63, TP64, TP65, TP66, TP67, TP68: TESTPOINTROUND1.5MM; TESTPOINT_ROUND_1.5MM
U$1, U$2, U$4, U$5, U$6, U$7, U$8, U$9, U$10, U$11, U$12, U$14, U$19, U$20, U$23, U$24, U$25, U$26, U$27, U$28, U$29, U$30, U$31, U$32, U$33, U$34, U$35, U$36, U$37, U$38, U$39, U$40, U$41, U$42, U$43, U$44, U$45, U$46, U$47, U$49, U$54, U$58, U$59, U$61, U$67, U$68, U$69, U$70, U$71, U$72, U$73, U$74, U$75, U$76, U$77, U$80: ELAST_10X10; ELAST_PAD_SQUARE_10MM_4X4WIDE

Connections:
COL0: TP12.P$1, U$1.P$1, U$4.P$1, U$8.P$1, U$12.P$1, U$26.P$1, U$30.P$1, U$54.P$1; also elsewhere on the board
COL1: TP13.P$1, U$2.P$1, U$5.P$1, U$9.P$1, U$23.P$1, U$27.P$1, U$31.P$1, U$58.P$1; also elsewhere on the board
COL2: TP14.P$1, U$6.P$1, U$10.P$1, U$14.P$1, U$25.P$1, U$28.P$1, U$32.P$1, U$59.P$1; also elsewhere on the board
COL3: TP15.P$1, U$7.P$1, U$11.P$1, U$20.P$1, U$24.P$1, U$29.P$1, U$49.P$1, U$61.P$1; also elsewhere on the board
COL4: TP16.P$1, U$19.P$1, U$36.P$1, U$40.P$1, U$44.P$1, U$67.P$1, U$71.P$1, U$75.P$1; also elsewhere on the board
COL5: TP17.P$1, U$33.P$1, U$37.P$1, U$41.P$1, U$45.P$1, U$68.P$1, U$72.P$1, U$76.P$1; also elsewhere on the board
COL6: TP18.P$1, U$34.P$1, U$38.P$1, U$43.P$1, U$46.P$1, U$69.P$1, U$73.P$1, U$77.P$1; also elsewhere on the board
COL7: TP19.P$1, U$35.P$1, U$39.P$1, U$42.P$1, U$47.P$1, U$70.P$1, U$74.P$1, U$80.P$1; also elsewhere on the board
GND: LED1.4 (GND), LED2.4 (GND), LED3.4 (GND), LED4.4 (GND), LED5.4 (GND), LED6.4 (GND), LED7.4 (GND), LED8.4 (GND), LED9.4 (GND), LED10.4 (GND), LED11.4 (GND), LED12.4 (GND), LED13.4 (GND), LED14.4 (GND), LED15.4 (GND), LED16.4 (GND), LED17.4 (GND), LED18.4 (GND), LED19.4 (GND), LED20.4 (GND), LED21.4 (GND), LED22.4 (GND), LED23.4 (GND), LED24.4 (GND), LED25.4 (GND), LED26.4 (GND), LED27.4 (GND), LED28.4 (GND), LED29.4 (GND), LED30.4 (GND), LED31.4 (GND), LED32.4 (GND), LED33.4 (GND), LED34.4 (GND), LED35.4 (GND), LED36.4 (GND), LED37.4 (GND), LED38.4 (GND), LED39.4 (GND), LED40.4 (GND), LED41.4 (GND), LED42.4 (GND), LED43.4 (GND), LED44.4 (GND), LED45.4 (GND), LED46.4 (GND), LED47.4 (GND), LED48.4 (GND), LED49.4 (GND), LED50.4 (GND), LED51.4 (GND), LED52.4 (GND), LED53.4 (GND), LED54.4 (GND), LED55.4 (GND), LED56.4 (GND); also elsewhere on the board
unnamed: D33.C, TP9.P$1, U$1.P$2
unnamed: D9.C, TP20.P$1, U$4.P$2
unnamed: D1.C, TP21.P$1, U$5.P$2
unnamed: D2.C, TP22.P$1, U$6.P$2
unnamed: D3.C, TP23.P$1, U$7.P$2
unnamed: D4.C, TP8.P$1, U$8.P$2
unnamed: LED17.3 (DO), LED18.1 (DI)
unnamed: LED18.3 (DO), LED19.1 (DI)
unnamed: D5.C, TP24.P$1, U$9.P$2
unnamed: LED19.3 (DO), LED20.1 (DI)
unnamed: LED1.3 (DO), LED2.1 (DI)
unnamed: LED2.3 (DO), LED3.1 (DI)
unnamed: LED3.3 (DO), LED4.1 (DI)
unnamed: LED4.3 (DO), LED5.1 (DI)
unnamed: D6.C, TP34.P$1, U$10.P$2
unnamed: LED5.3 (DO), LED6.1 (DI)
unnamed: LED6.3 (DO), LED7.1 (DI)
unnamed: D7.C, TP25.P$1, U$11.P$2
unnamed: LED7.3 (DO), LED8.1 (DI)
unnamed: D8.C, TP33.P$1, U$12.P$2
unnamed: LED8.3 (DO), LED9.1 (DI)
unnamed: D10.C, TP26.P$1, U$23.P$2
unnamed: D11.C, TP32.P$1, U$25.P$2
unnamed: D12.C, TP27.P$1, U$24.P$2
unnamed: D13.C, TP31.P$1, U$26.P$2
unnamed: D14.C, TP28.P$1, U$27.P$2
unnamed: D15.C, TP30.P$1, U$28.P$2
unnamed: D16.C, TP29.P$1, U$29.P$2
unnamed: LED9.3 (DO), LED10.1 (DI)
unnamed: LED10.3 (DO), LED12.1 (DI)
unnamed: LED11.1 (DI), LED12.3 (DO)
unnamed: LED11.3 (DO), LED13.1 (DI)
unnamed: LED13.3 (DO), LED14.1 (DI)
unnamed: LED14.3 (DO), LED15.1 (DI)
unnamed: LED15.3 (DO), LED16.1 (DI)
unnamed: LED20.3 (DO), LED21.1 (DI)
unnamed: LED21.3 (DO), LED22.1 (DI)
unnamed: LED22.3 (DO), LED23.1 (DI)
unnamed: LED23.3 (DO), LED24.1 (DI)
unnamed: LED24.3 (DO), LED25.1 (DI)
unnamed: LED25.3 (DO), LED26.1 (DI)
unnamed: LED26.3 (DO), LED28.1 (DI)
unnamed: LED27.1 (DI), LED28.3 (DO)
unnamed: LED27.3 (DO), LED29.1 (DI)
unnamed: LED29.3 (DO), LED30.1 (DI)
unnamed: LED30.3 (DO), LED31.1 (DI)
unnamed: LED31.3 (DO), LED32.1 (DI)
unnamed: D17.C, TP35.P$1, U$19.P$2
unnamed: D18.C, TP36.P$1, U$33.P$2
unnamed: D19.C, TP38.P$1, U$34.P$2
unnamed: D20.C, TP37.P$1, U$35.P$2
unnamed: D21.C, TP39.P$1, U$36.P$2
unnamed: D22.C, TP40.P$1, U$37.P$2
unnamed: D23.C, TP42.P$1, U$38.P$2
unnamed: D24.C, TP41.P$1, U$39.P$2
unnamed: D25.C, TP43.P$1, U$40.P$2
unnamed: D26.C, TP44.P$1, U$41.P$2
unnamed: D27.C, TP46.P$1, U$43.P$2
unnamed: D28.C, TP45.P$1, U$42.P$2
unnamed: D29.C, TP47.P$1, U$44.P$2
unnamed: D30.C, TP49.P$1, U$45.P$2
unnamed: D31.C, TP48.P$1, U$46.P$2
unnamed: D32.C, TP50.P$1, U$47.P$2
unnamed: LED16.3 (DO), LED17.1 (DI)
unnamed: D35.C, TP5.P$1, U$2.P$2
unnamed: D36.C, TP7.P$1, U$14.P$2
unnamed: D37.C, TP6.P$1, U$20.P$2
unnamed: D38.C, TP52.P$1, U$30.P$2
unnamed: D39.C, TP10.P$1, U$31.P$2
unnamed: D40.C, TP51.P$1, U$32.P$2
unnamed: D41.C, TP11.P$1, U$49.P$2
unnamed: D42.C, TP56.P$1, U$54.P$2
unnamed: D43.C, TP53.P$1, U$58.P$2
unnamed: D44.C, TP55.P$1, U$59.P$2
unnamed: D45.C, TP54.P$1, U$61.P$2
unnamed: D46.C, TP60.P$1, U$67.P$2
unnamed: D47.C, TP57.P$1, U$68.P$2
unnamed: D48.C, TP59.P$1, U$69.P$2
unnamed: D49.C, TP58.P$1, U$70.P$2
unnamed: D50.C, TP64.P$1, U$71.P$2
unnamed: D51.C, TP61.P$1, U$72.P$2
unnamed: D52.C, TP63.P$1, U$73.P$2
unnamed: D53.C, TP62.P$1, U$74.P$2
unnamed: D54.C, TP68.P$1, U$75.P$2
unnamed: D55.C, TP65.P$1, U$76.P$2
unnamed: D56.C, TP67.P$1, U$77.P$2
unnamed: D57.C, TP66.P$1, U$80.P$2
unnamed: LED33.3 (DO), LED34.1 (DI)
unnamed: LED34.3 (DO), LED36.1 (DI)
unnamed: LED35.1 (DI), LED36.3 (DO)
unnamed: LED35.3 (DO), LED37.1 (DI)
unnamed: LED37.3 (DO), LED38.1 (DI)
unnamed: LED38.3 (DO), LED39.1 (DI)
unnamed: LED39.3 (DO), LED40.1 (DI)
unnamed: LED41.3 (DO), LED42.1 (DI)
unnamed: LED42.3 (DO), LED44.1 (DI)
unnamed: LED43.1 (DI), LED44.3 (DO)
unnamed: LED43.3 (DO), LED45.1 (DI)
unnamed: LED45.3 (DO), LED46.1 (DI)
unnamed: LED46.3 (DO), LED47.1 (DI)
unnamed: LED47.3 (DO), LED48.1 (DI)
unnamed: LED49.3 (DO), LED50.1 (DI)
unnamed: LED50.3 (DO), LED52.1 (DI)
unnamed: LED51.1 (DI), LED52.3 (DO)
unnamed: LED51.3 (DO), LED53.1 (DI)
unnamed: LED53.3 (DO), LED54.1 (DI)
unnamed: LED54.3 (DO), LED55.1 (DI)
unnamed: LED55.3 (DO), LED56.1 (DI)
unnamed: LED40.3 (DO), LED41.1 (DI)
unnamed: LED48.3 (DO), LED49.1 (DI)
unnamed: LED32.3 (DO), LED33.1 (DI)
NEOPIXEL_5V: LED1.1 (DI); also elsewhere on the board
ROW0: D1.A, D2.A, D3.A, D9.A, D17.A, D18.A, D19.A, D20.A; also elsewhere on the board
ROW1: D4.A, D5.A, D6.A, D7.A, D21.A, D22.A, D23.A, D24.A; also elsewhere on the board
ROW2: D8.A, D10.A, D11.A, D12.A, D25.A, D26.A, D27.A, D28.A; also elsewhere on the board
ROW3: D13.A, D14.A, D15.A, D16.A, D29.A, D30.A, D31.A, D32.A; also elsewhere on the board
ROW4: D33.A, D35.A, D36.A, D37.A, D46.A, D47.A, D48.A, D49.A; also elsewhere on the board
ROW5: D38.A, D39.A, D40.A, D41.A, D50.A, D51.A, D52.A, D53.A; also elsewhere on the board
ROW6: D42.A, D43.A, D44.A, D45.A, D54.A, D55.A, D56.A, D57.A; also elsewhere on the board
VDD: LED1.2 (VDD), LED2.2 (VDD), LED3.2 (VDD), LED4.2 (VDD), LED5.2 (VDD), LED6.2 (VDD), LED7.2 (VDD), LED8.2 (VDD), LED9.2 (VDD), LED10.2 (VDD), LED11.2 (VDD), LED12.2 (VDD), LED13.2 (VDD), LED14.2 (VDD), LED15.2 (VDD), LED16.2 (VDD), LED17.2 (VDD), LED18.2 (VDD), LED19.2 (VDD), LED20.2 (VDD), LED21.2 (VDD), LED22.2 (VDD), LED23.2 (VDD), LED24.2 (VDD), LED25.2 (VDD), LED26.2 (VDD), LED27.2 (VDD), LED28.2 (VDD), LED29.2 (VDD), LED30.2 (VDD), LED31.2 (VDD), LED32.2 (VDD), LED33.2 (VDD), LED34.2 (VDD), LED35.2 (VDD), LED36.2 (VDD), LED37.2 (VDD), LED38.2 (VDD), LED39.2 (VDD), LED40.2 (VDD), LED41.2 (VDD), LED42.2 (VDD), LED43.2 (VDD), LED44.2 (VDD), LED45.2 (VDD), LED46.2 (VDD), LED47.2 (VDD), LED48.2 (VDD), LED49.2 (VDD), LED50.2 (VDD), LED51.2 (VDD), LED52.2 (VDD), LED53.2 (VDD), LED54.2 (VDD), LED55.2 (VDD), LED56.2 (VDD); also elsewhere on the board

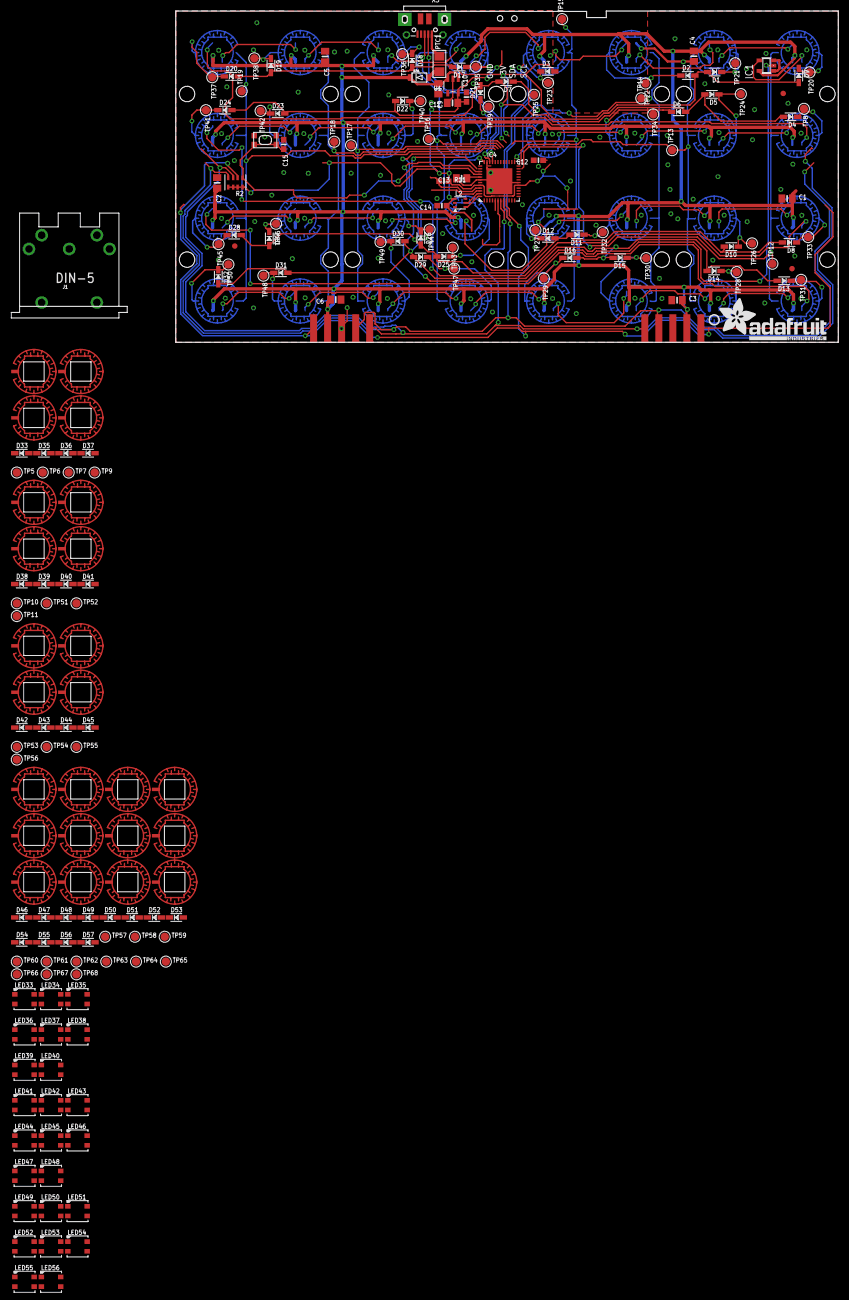
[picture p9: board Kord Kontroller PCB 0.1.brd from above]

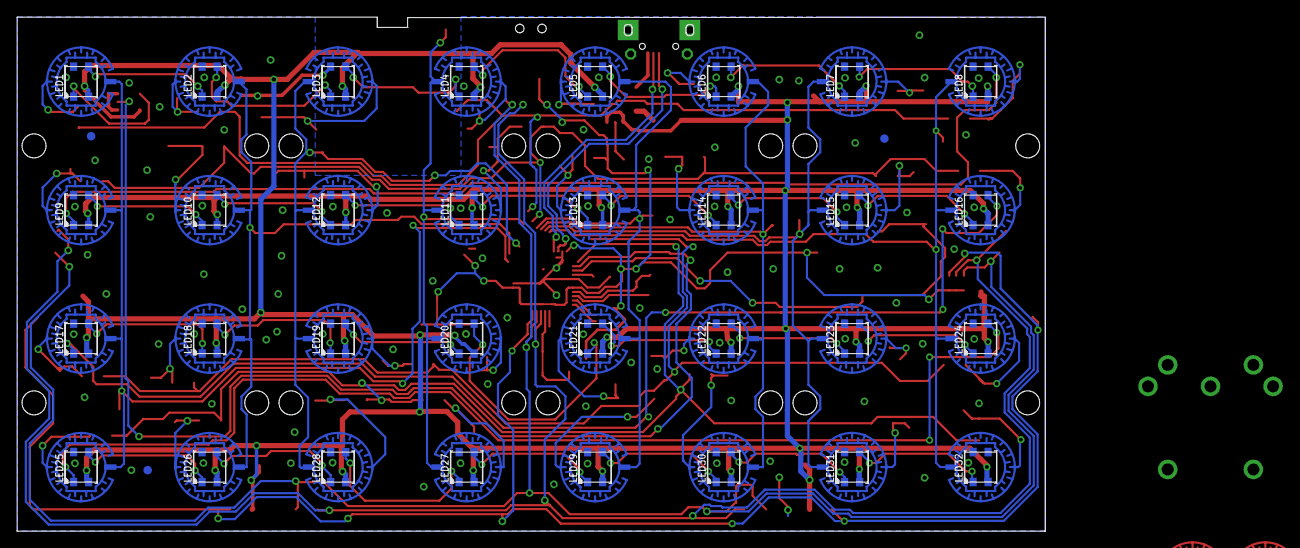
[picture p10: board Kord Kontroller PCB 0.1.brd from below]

Board: 2 copper layers, 120.0 x 60.0 mm, 267 parts (67 on the bottom side), 143 nets.

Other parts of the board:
IC1: 74HCT1G125DBV; SOT23-5
J1: DIN5; DIN5-RA-PTH
U$3: ADAFRUIT_TEXT_20MM
U$48: TRELLISLOGO
U$78: PCBFEAT-REV-040

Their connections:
GND: IC1.1, IC1.3; also elsewhere on the board
NEOPIXEL_3V: IC1.2; also elsewhere on the board
NEOPIXEL_5V: IC1.4; also elsewhere on the board
VDD: IC1.5; also elsewhere on the board

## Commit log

2019-07-23 Adding board and schematics
2019-07-23 adding board and schematic
    [Kord Kontroller PCB 0.1.brd, Kord Kontroller PCB 0.1.sch, Kord Kontroller PCB 0.2.brd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]
2019-08-05 Added lines to new 64-QFN part
    [Kord Kontroller PCB 0.2.brd, Kord Kontroller PCB 0.2.sch]
2019-08-07 Deleted TQFN8 pin package for 64 pin package
    [Kord Kontroller PCB 0.2.brd, Kord Kontroller PCB 0.2.sch]
2019-08-20 traced routes for LEDs and half the board
    [Kord Kontroller PCB 0.2.brd, Kord Kontroller PCB 0.2.sch]
2019-08-28 Added Routes for Cols 0-6, Finished Rows and diodes
    [Kord Kontroller PCB 0.2.brd, Kord Kontroller PCB 0.2.sch]
2019-08-29 Added traces for 7-14
    [Kord Kontroller PCB 0.2.brd, Kord Kontroller PCB 0.2.sch]
2019-08-29 added last top button diodes
    [Kord Kontroller PCB 0.2.brd]
2019-09-01 routed power and midi
    [Kord Kontroller PCB 0.2.brd, Kord Kontroller PCB 0.2.sch]
2019-09-02 Finished Routinggit status
    [Kord Kontroller PCB 0.2.brd]
2019-09-07 Added VDD plane and GND plane
    [Kord Kontroller PCB 0.2.brd, Kord Kontroller PCB 0.2.sch]
2019-09-08 cleaned up 90 degrees and vias
    [Kord Kontroller PCB 0.2.brd]
2019-09-29 Switched pieces to bottom
    [Kord Kontroller PCB 0.2.brd, Kord Kontroller PCB 0.2.sch]
2019-10-04 Added osc and reourting diodes
    [Kord Kontroller PCB 0.2.brd, Kord Kontroller PCB 0.2.sch]
2019-10-05 Moved resistors to bottom and Added 32k crystal
    [Kord Kontroller PCB 0.2.brd, Kord Kontroller PCB 0.2.sch]
2019-10-05 Moved resistor a little
    [Kord Kontroller PCB 0.2.brd]
2019-10-05 added a logo
    [Kord Kontroller PCB 0.2.brd]
2019-10-05 Minor resistor change
    [Kord Kontroller PCB 0.2.brd]
2019-10-06 moved some stuff around
    [Kord Kontroller PCB 0.2.brd, Kord Kontroller PCB 0.2.sch]
2019-10-17 Rotated LEDs to remove DRC errors
    [Kord Kontroller PCB 0.2.brd, Kord Kontroller PCB 0.2.sch]
2019-11-24 Removed wire stubs
    [Kord Kontroller PCB 0.2.brd]
2019-12-26 Changed USB package and removed most of the errorsgit stash
    [Kord Kontroller PCB 0.2.brd, Kord Kontroller PCB 0.2.sch]
2020-01-06 Removed AIRWIRE
    [Kord Kontroller PCB 0.2.brd]
2020-01-07 FINAL SENT
    [Kord Kontroller PCB 0.2.brd]
2020-01-07 FINAL SENT first board
    [Kord Kontroller PCB 0.2.brd]
2020-01-09 changed crystal
    [Kord Kontroller PCB 0.2.brd, Kord Kontroller PCB 0.2.sch]
2020-01-09 Level shifter and decouplers
    [Kord Kontroller PCB 0.2.brd, Kord Kontroller PCB 0.2.sch]
2020-01-10 Rerouted, gave better routes, switched voltage shifter part
    [Kord Kontroller PCB 0.2.brd, Kord Kontroller PCB 0.2.sch]
2020-01-10 Moved caps
    [Kord Kontroller PCB 0.2.brd]
2020-01-10 Fixed some right angle traces
    [Kord Kontroller PCB 0.2.brd]
2020-01-10 3.3 v missing trace
    [Kord Kontroller PCB 0.2.brd]
2020-01-10 Board REV A
    [Kord Kontroller PCB 0.2.brd]

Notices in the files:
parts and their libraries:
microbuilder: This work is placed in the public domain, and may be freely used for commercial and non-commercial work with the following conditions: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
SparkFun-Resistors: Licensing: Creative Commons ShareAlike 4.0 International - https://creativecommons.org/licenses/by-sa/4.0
